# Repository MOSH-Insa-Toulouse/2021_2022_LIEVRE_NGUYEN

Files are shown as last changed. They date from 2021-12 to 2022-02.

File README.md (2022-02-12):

# 2021_2022_LIEVRE_NGUYEN
This project is part of the 5ISS year formation at INSA Toulouse. We created a nanoparticle gas sensor in the AIME laboratory at INSA Toulouse.
Then, we designed the PCB and the code to use the sensor with a  and display its data on a dashboard.

## SOMMAIRE 
1. [Introduction](#intro)
2. [Lora](#p2)
3. [LoraWAN](#p3)
4. [TTN](#p4)
5. [KiCad](#p5) 
6. [Node-RED](#p6)
7. [Datasheet](#p7)
8. [Possible improvements](#p8)
9. [Contacts](#p9)

## Introduction 

This project allowed us to go further in the development of our sensor. 
Indeed, we can now use it with a shield, connect it to TTN and see the data on a Node-RED dashboard. The arduino code used to retrieve and process the data was adapted for both the AIME gaz sensor and the industrial grove sensor given to us. We used a ESP32 as a microcontroller.

Here, you will find :

- [x] The arduino code of the sensor to collect data, alert the user and connect it to TTN.
- [x] The PCB shield along with the KiCad project.
- [x] The Node-RED flow for the dashboard.
- [x] The sensor's datasheet.

Here is a picture of our circuit: <br>
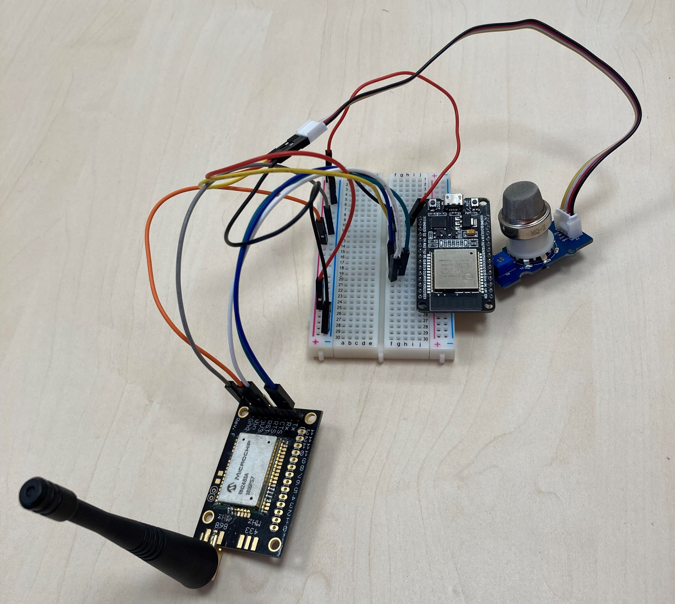
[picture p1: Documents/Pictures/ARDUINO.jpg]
 <br>

## Lora 

First, we tested the LoRa connexion with a small code.
To test it, we used a very simple circuit:
- RST connected to D21
- Rx connected to D19
- Tx connected to D18

You can find the code below:

<details>
  <summary><b>Tx</b></summary>
   To send a message, you need to enter the following command : "radio tx" + hexa_msg

```c++
  #include <Arduino.h>
  #include <HardwareSerial.h>
  #include "rn2xx3.h"

  #define RXD2 18
  #define TXD2 19
  #define RESET 21

  rn2xx3 lora(Serial2);

  void initialize_radio()
  {
    pinMode(RESET, OUTPUT);
    digitalWrite(RESET, LOW);
    delay(100);
    digitalWrite(RESET, HIGH);

    delay(100); //wait for the RN2xx3's startup message
    Serial2.flush();
  }

  void setup()
  {
    Serial.begin(9600);
    Serial2.begin(57600, SERIAL_8N1, RXD2, TXD2);
    initialize_radio();
    Serial.println(Serial2.readStringUntil('\n'));
    Serial2.print("radio set pwr 14\r\n");
    Serial.println(Serial2.readStringUntil('\n'));
    Serial2.print("mac pause\r\n");
    Serial.println(Serial2.readStringUntil('\n'));
  }

  void loop()
  {
    if(Serial2.available()) {
      Serial.println(Serial2.readStringUntil('\n'));
    }
    if (Serial.available())
    { 
      String Command = Serial.readStringUntil('\n');
      Serial.println(Command);
      Serial2.print(Command + "\r\n");
    }
  }
```
</details>

<details>
  <summary><b>Rx</b></summary>

``` c++
  #include <Arduino.h>
  #include <HardwareSerial.h>
  #include "rn2xx3.h"

  #define RXD2 18
  #define TXD2 19
  #define RESET 21

  rn2xx3 lora(Serial2);

  void initialize_radio()
  {
    //reset RN2xx3
    pinMode(RESET, OUTPUT);
    digitalWrite(RESET, LOW);
    delay(100);
    digitalWrite(RESET, HIGH);

    delay(100); //wait for the RN2xx3's startup message
    Serial2.flush();
  }

  void setup()
  {
    Serial.begin(9600);
    Serial2.begin(57600, SERIAL_8N1, RXD2, TXD2);
    initialize_radio();
    Serial.println(Serial2.readStringUntil('\n'));
    Serial2.print("radio set pwr 14\r\n");
    Serial.println(Serial2.readStringUntil('\n'));
    Serial2.print("mac pause\r\n");
    Serial.println(Serial2.readStringUntil('\n'));
  }

  void loop()
  {
    Serial2.print("radio rx 0\r\n");
    if(Serial2.available()) {
      Serial.println(Serial2.readStringUntil('\n'));
    }
    if (Serial.available())
    { 
      String Command = Serial2.readStringUntil('\n');
      Serial.println(Command);
    }
    delay(1000);
  }
```
</details>

You can also find the codes:
- [here for Tx](https://github.com/MOSH-Insa-Toulouse/2021_2022_LIEVRE_NGUYEN/tree/main/Piste_verte/Lora_Tx_mod2mod.ino)
- [here for Rx](https://github.com/MOSH-Insa-Toulouse/2021_2022_LIEVRE_NGUYEN/tree/main/Piste_verte/Lora_Rx_mod2mod.ino)

## LoraWAN 

In this part, we implemented the full arduino code that retrieves and sends to TTN via LoraWAN the value of both the grove and AIME sensor. 
We also read the raw value of the resistor (R_alu) that serves as a temperature sensor. By using the R_alu value, we then deduced the temperature.
We also implemented a PID controller to maintain the temperature of the silicium resistor R_Poly to a temperature of 200°C. To do so, we use the PID controller to generate a duty cycle that is then entered as a parameter for the PWM signal that controls the silicium rod that serves as R_poly.

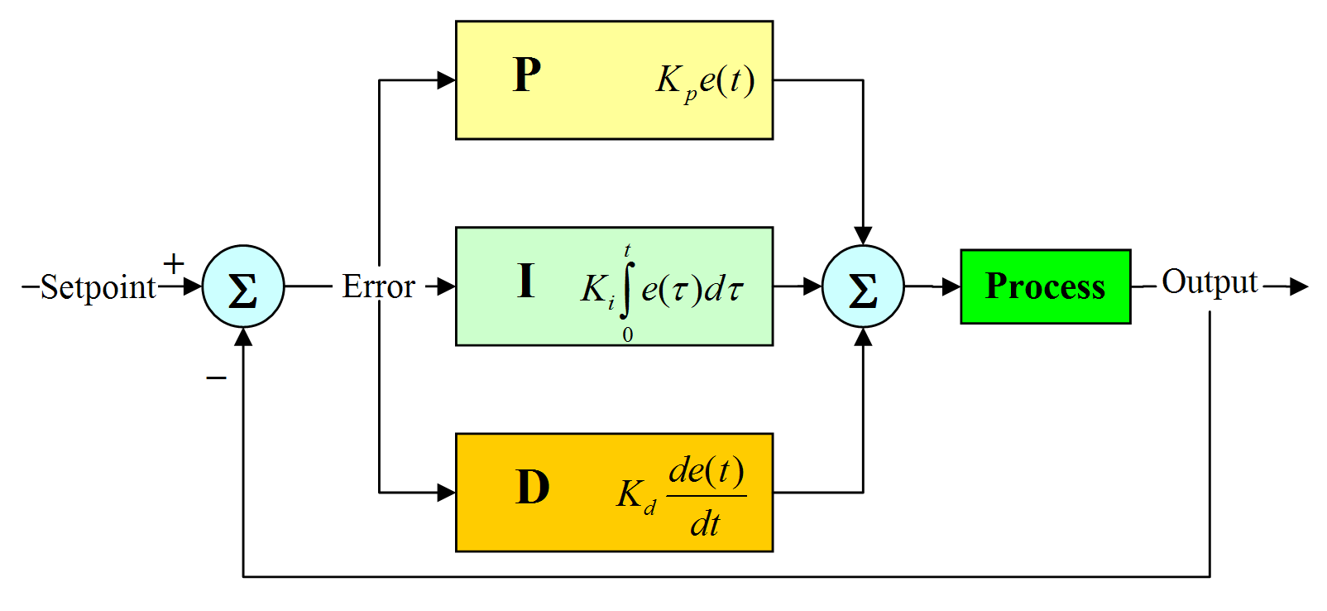
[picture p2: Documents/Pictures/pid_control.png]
 <br>

<details>
  <summary><b>You can find the code directly here</b></summary>

```c++
  #include <Arduino.h>
  #include "rn2xx3.h"

  #define RESET 21 //Pin Reset LoRA
  #define RX 18    //Pin RX LoRa
  #define TX 19    //Pin TX LoRa
  #define INTERRUPT_PIN 12 //Pin d'interruption du capteur de gaz grove
  #define PWM_PIN 16   //Pin de sortie de la commande PWM (vers transistor -> R_poly (barreau silicium))
  #define GROVE_PIN 4  //Signal d'entree du capteur grove 
  #define CMD_R_POLY 7 //Pin de la sortie de commande de la resistance de chauffe (barreau silicium)
  #define ADC_SENSOR 33 // Pin d'entree du signal du capteur de gaz (AIME)
  #define ADC_R_ALU 27 //Pin d'entree de la resistance d'aluminium (capteur de temperature)
  #define BUZZER_PIN 17  //Pin de sortie du buzzer

  #define gaz_threshold 1E8 //Valeur seuil pour déclencher l'alarme (buzzer)
   
  //Correcteur PID
  float e_curr = 0; //erreur à t
  float e_prev = 0; //erreur à t-1
  int prev_T = 0; //timestamp 1
  int curr_T = 0; //timestamp 2
  float target_temp = 200; // Température de R_poly voulue

  //Paramètres TTN
  String AppEUI = "0000000000000000";
  String AppKey = "27C93ED04348754075826C46CE00F53D";

  //Capteur de température (Alu)
  int a; //
  int b; // R_aluminium = a * T(Kelvin) + b 

  // Pour la commande PWM de la résistance de chauffe
  int duty_cycle; //duty cycle du signal PWM pour la commande de la résistance de chauffe
  const uint32_t PWM_fq = 20000;
  const uint32_t PWMChannel = 0;
  const uint32_t resolution = 8;

  // Pour le capteur grove
  float sensor_grove_volt; //conversion en volt de l'entree du signal du capteur grove
  float RS_gas; //valeur de RS dans le gaz
  float R0 = 1.7; //résistance du module grove en environnement ambiant 
  float ratio; // ratio RS_GAS/RS_air
  uint32_t ratio_int;
  uint32_t grove_data; //données capteur grove

  // Pour le capteur AIME
  float sensor_aime_volt; //conversion en volt de l'entree du signal du capteur AIME
  uint32_t AIME_data;  //données capteur AIME
  int R1 = 100000;
  int R2 = 1000;
  int R3 = 100000;
  int R4;
  int R5 = 10000;
  int R6; //resistances du circuit de conditionnement (cf circuit Kicad)
  int Vcc; // à definir en fonction des grandeurs electriques voulues

  rn2xx3 lora(Serial2); //Constructeur de la classe rn2xx3

  //Initialisation du module LoRa
  void init_Lora(){
    
    //reset RN2xx3
    pinMode(RESET, OUTPUT);
    digitalWrite(RESET, LOW);
    delay(100);
    digitalWrite(RESET, HIGH);
    delay(100); //Attente le startup message du module RN2xx3 
    Serial2.flush();
    //Vérification de la communication avec la radio
    String hweui = lora.hweui();
    while (hweui.length() != 16)
    {
      Serial.println("Communication with RN2xx3 unsuccessful. Power cycle the board.");
      Serial.println(hweui);
      delay(10000);
      hweui = lora.hweui();
    }

    //Retourne le HWEUI pour l'inscrire via ttnctl
    Serial.println("When using OTAA, register this DevEUI: ");
    Serial.println(hweui);
    Serial.println("RN2xx3 firmware version:");
    Serial.println(lora.sysver());
    
    Serial.println("Trying to join TTN");
    bool join_result = false;
    //OTAA: initOTAA(String AppEUI, String AppKey);
    join_result = lora.initOTAA(AppEUI, AppKey);

    while (!join_result)
    {
      Serial.println("Unable to join. Are your keys correct, and do you have TTN coverage?");
      delay(60000); //Attente d'une minute avant de réessayer
      join_result = lora.init();
    }
    Serial.println("Successfully joined TTN");
  }

  //Lecture du capteur grove
  uint32_t read_grove() 
  {
    int sensor_grove_value = analogRead(GROVE_PIN); 
    sensor_grove_volt=(float)sensor_grove_value/4096*5.0; //tension du capteur
    RS_gas = (5.0-sensor_grove_volt)/ sensor_grove_volt; // taux de variation de la résistance selon le gaz
    ratio = (RS_gas/R0);  // ratio = RS/R0
    uint32_t data_sensor = ratio*100;
    return data_sensor;
  }

  //Lecture du capteur AIME
  uint32_t read_AIME(){ 
    
    int sensor_aime_value = analogRead(ADC_SENSOR);
    sensor_aime_volt=(float)sensor_aime_value/4096*5.0;
    float R_sensor=(R1*(R2+R3)*Vcc/(R2*sensor_aime_volt))-R1-R5; 
    return R_sensor;
  }

  //Lecture de la résistance du capteur de température
  uint32_t read_r_alu (){
    int adc_R_alu = analogRead(ADC_R_ALU);
    float adc_R_alu_volt=(float)ADC_R_ALU/4096*3.3;
    float R_Alu=adc_R_alu_volt*R6/(3.3-adc_R_alu_volt);
    return R_Alu;
  }

  //Calcul de la temperature du capteur avec R aluminium
  float read_temperature(){
    
    float temp = a*(read_r_alu()) + b;
    temp = temp - 273; //conversion en C°
    return temp;
  }

  //Correcteur PID pour maintenir la température du R_poly à 200 °C
  int corr_PID(int Kp, int Ki, int Kd){

    int curr_T = micros();
    float delta_t=((float)(curr_T - prev_T))/1E6; 
    e_curr = target_temp - read_temperature(); 
    float e_P = e_curr; //partie proportionnelle
    float e_I = (e_I + e_curr * delta_t); //partie intégrale
    float e_D = (e_curr - e_prev) / (delta_t); //partie dérivatrice
    prev_T = curr_T;
    e_prev = e_curr;
    uint8_t C = Kp * e_P + Ki * e_I+ Kd * e_D;
    if(C > 255) {
      C = 255; //Pour borner la correction entre 0 et 255
    }
    return C; //Duty cycle de la PWM de commande
   
  }

  //Configuration PWM
  void config_PWM(){
    pinMode(PWM_PIN,OUTPUT);
    ledcSetup(PWMChannel, PWM_fq, resolution);
    ledcAttachPin(PWM_PIN, PWMChannel); //Liaison de la channel avec le pin PWM pour le contrôler
  }

  //Commande de la resistance de chauffe en PWM
  void cmd_PWM_Poly(){
    int duty_cycle=corr_PID(1,0,0);
    ledcWrite(PWMChannel,duty_cycle);
  }

  void setup() {
    Serial.begin(9600);
    config_PWM(); 
    Serial2.begin(57600, SERIAL_8N1, RX, TX);
    init_Lora();
    if (Serial.available()){
      Serial2.print("sys get hwei\r\n"); // recuperation du HWEUI
      Serial.println(Serial2.readStringUntil('\n'));
    }
    digitalWrite(BUZZER_PIN, 0); //inititialisation du buzzer
    
  }

  void loop() {

    cmd_PWM_Poly();
    grove_data=read_grove();
    AIME_data=read_AIME();
    if(AIME_data > gaz_threshold){

      byte payload[4]; //Payload a envoyer sur TTN
      payload[0] = highByte(grove_data);
      payload[1] = lowByte(grove_data);
      payload[2]=highByte(AIME_data);  
      payload[1]=lowByte(AIME_data);
      lora.txBytes(payload,4); 
      
      for (int i=0;i<5; i++){
        digitalWrite(BUZZER_PIN, 1); //active l'alarme à la detection de gaz
        delay(10000);
      }
      digitalWrite(BUZZER_PIN, 0); //inititialisation du buzzer
    
    }
    
  }
```
</details>

You can also find the code [here](https://github.com/MOSH-Insa-Toulouse/2021_2022_LIEVRE_NGUYEN/tree/main/Piste_rouge/Piste_bleue_code)

## TTN 

We configured an application whose overview is shown in the next picture:

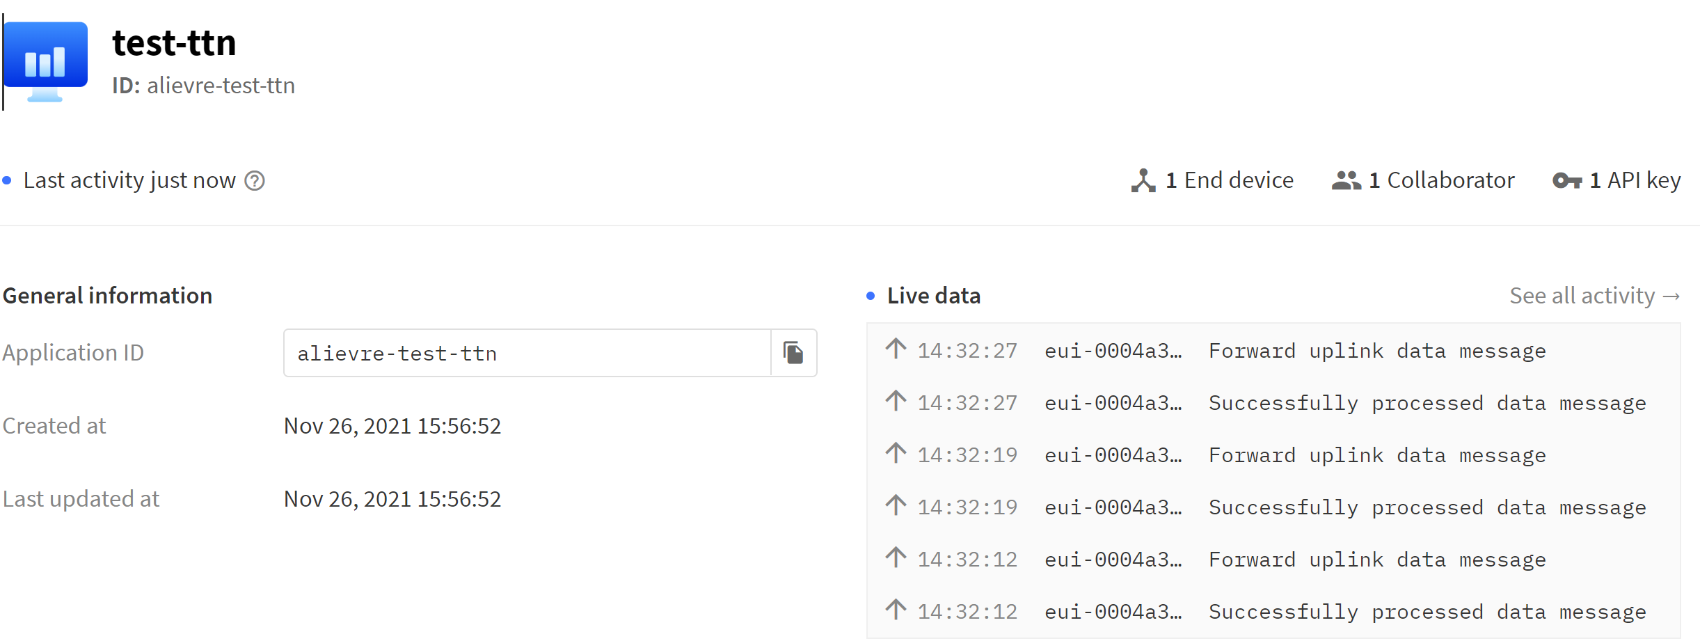
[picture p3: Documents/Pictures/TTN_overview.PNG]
TTN_overview


In this app, we added a device:

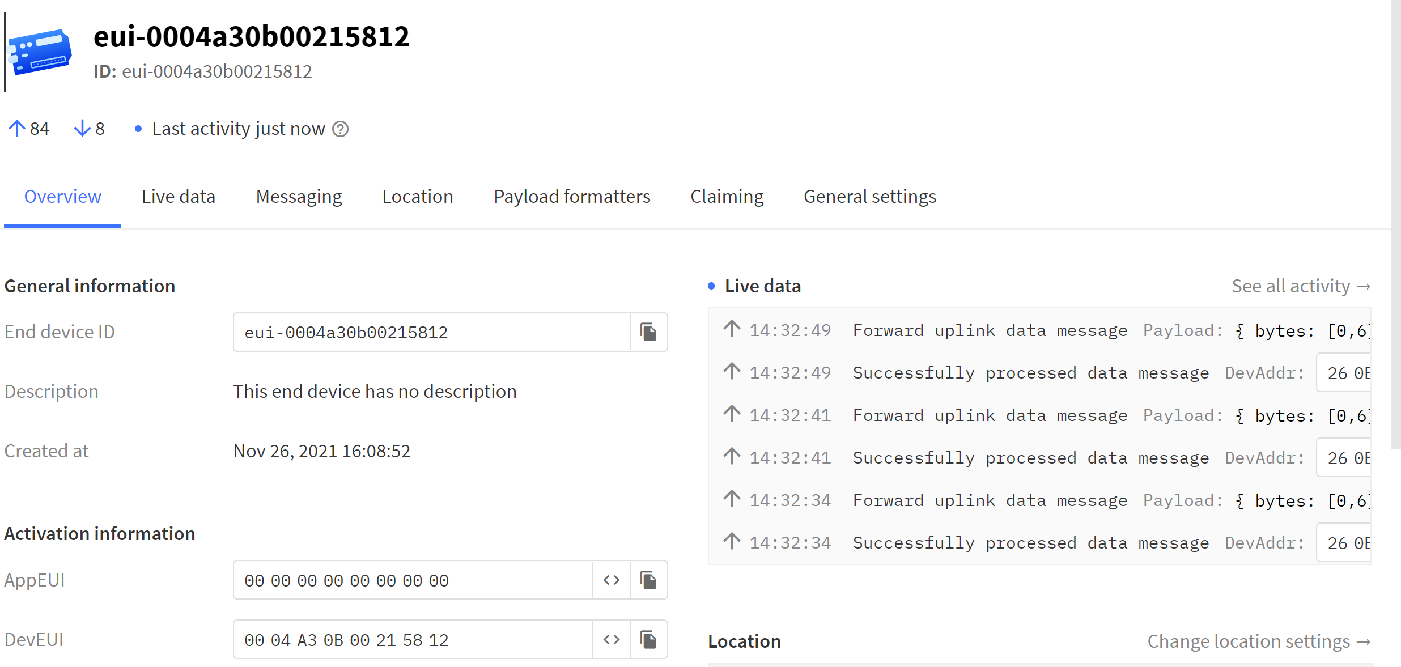
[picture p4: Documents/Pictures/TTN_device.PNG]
TTN_device

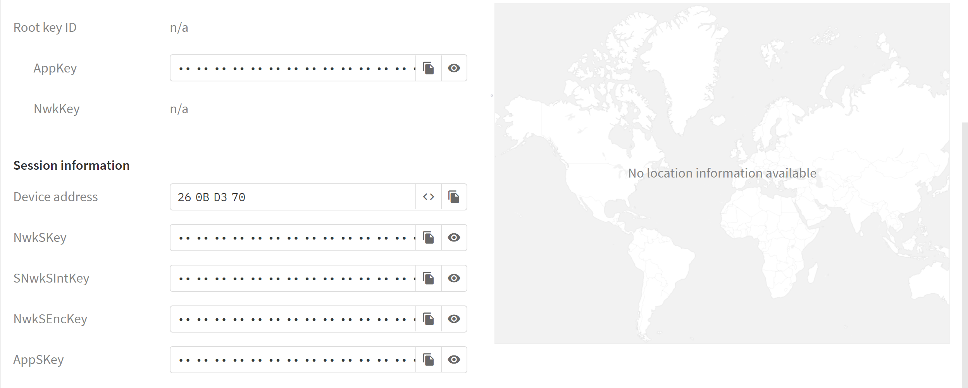
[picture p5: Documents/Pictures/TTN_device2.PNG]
TTN_device2


You can see that we received live data:

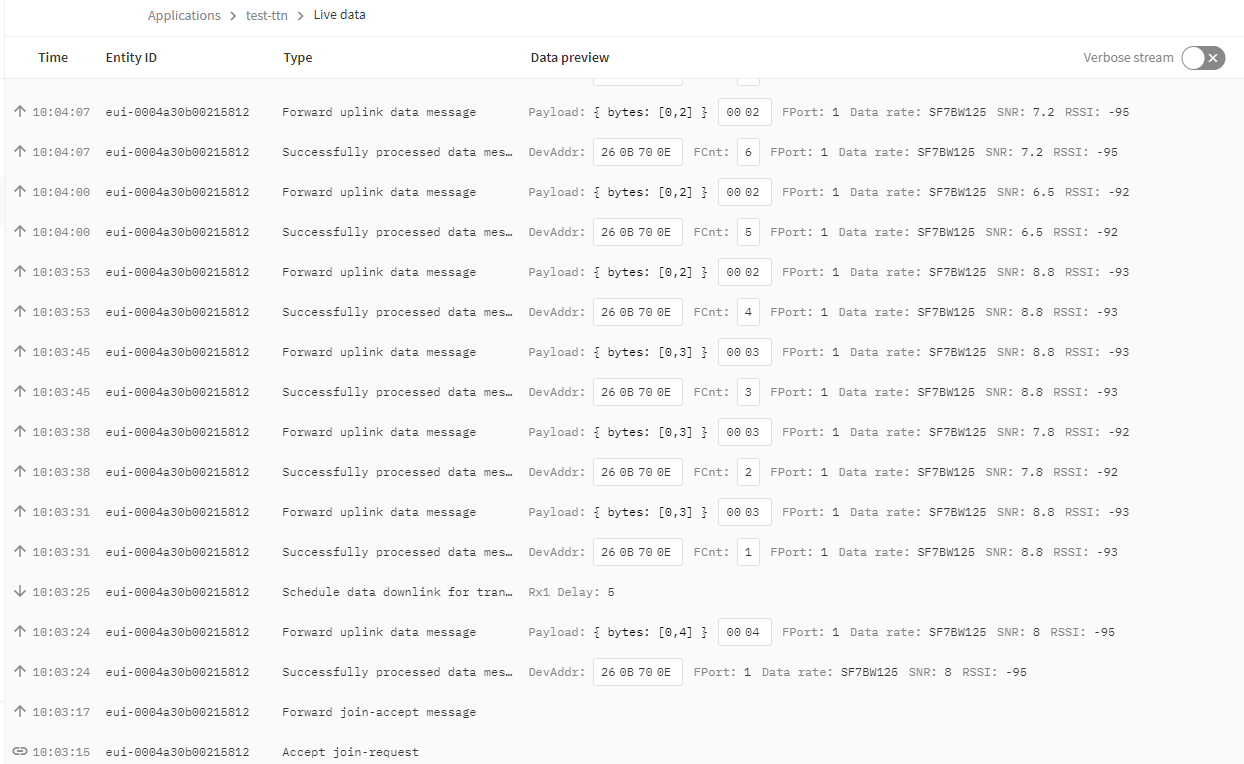
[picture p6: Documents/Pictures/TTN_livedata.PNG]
TTN_livedata


We also added a payload formatter: <br>

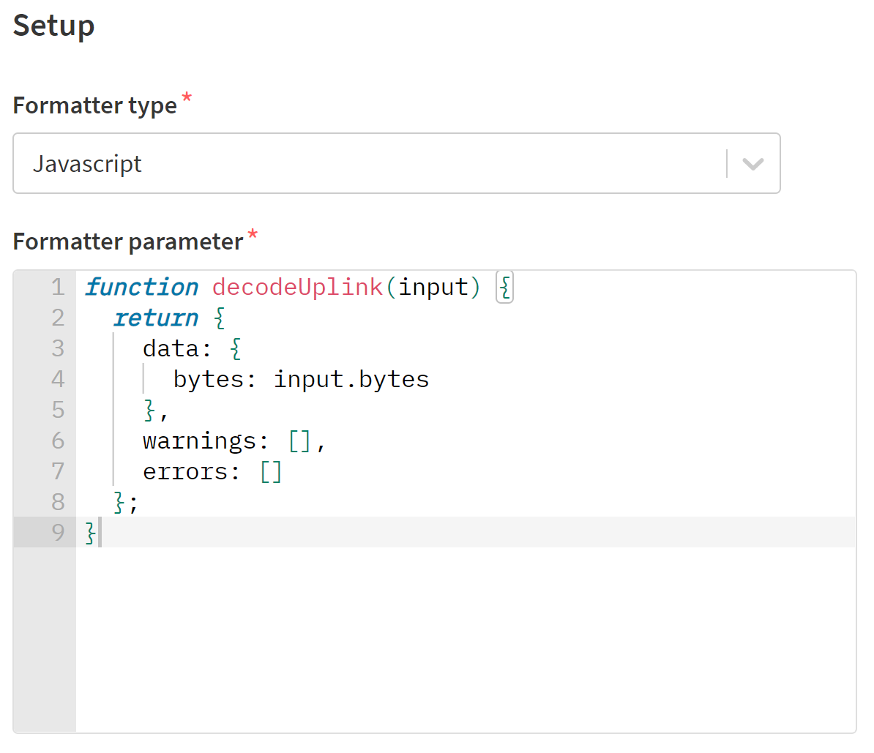
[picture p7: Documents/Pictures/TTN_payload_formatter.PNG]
 <br>

## KiCad 

We then proceeded to conceive the PCB shield.
The first thing to do is to draw the circuit. We used the following circuit:
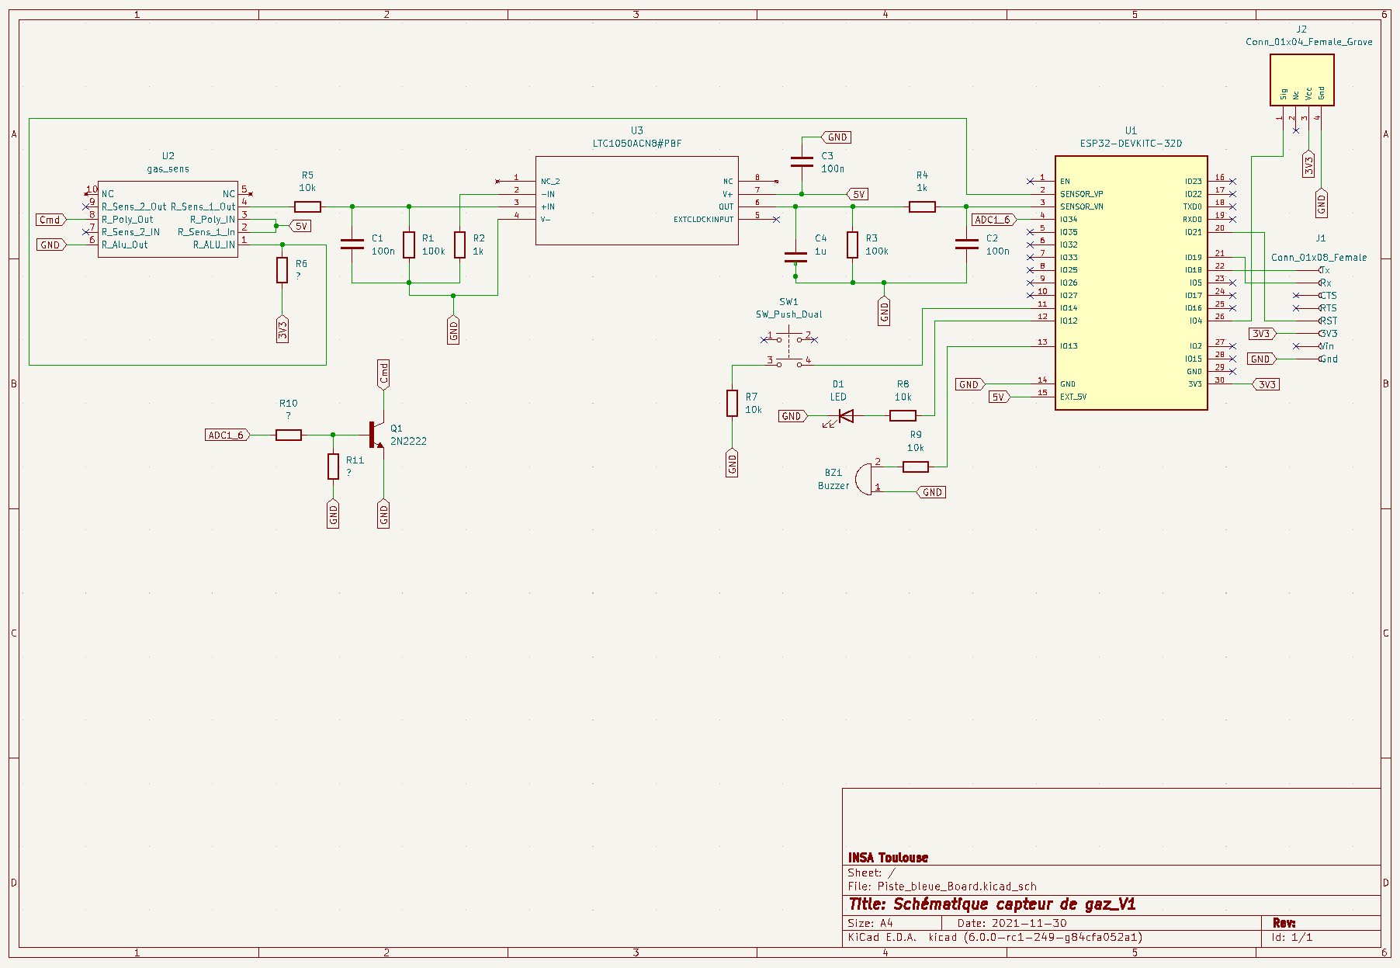
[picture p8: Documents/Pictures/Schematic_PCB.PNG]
Schematic_PCB


Then, we needed the footprint of each elements. <br> <br>
- Buzzer

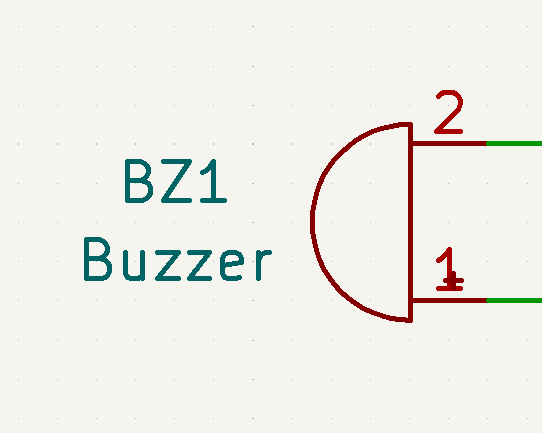
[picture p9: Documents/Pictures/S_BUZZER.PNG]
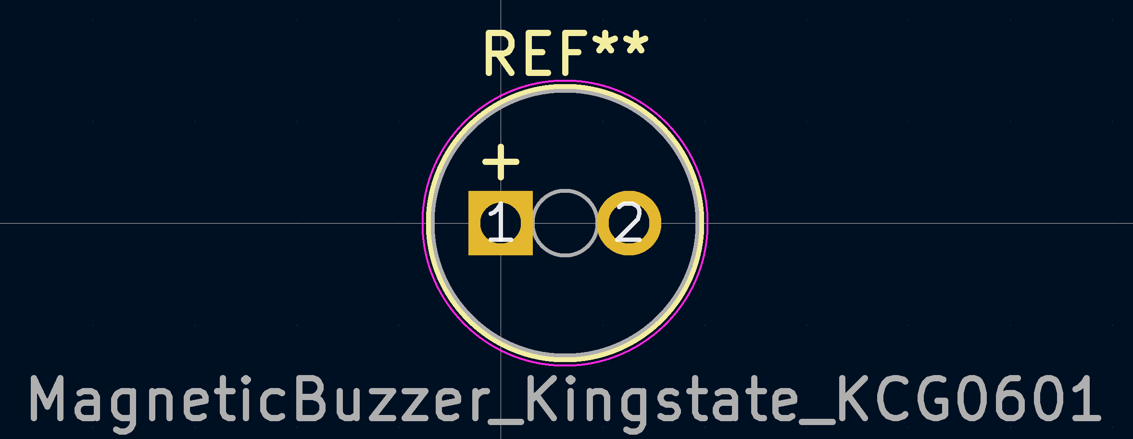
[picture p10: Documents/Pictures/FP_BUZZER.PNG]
 &emsp;  <br>

- Capacitor

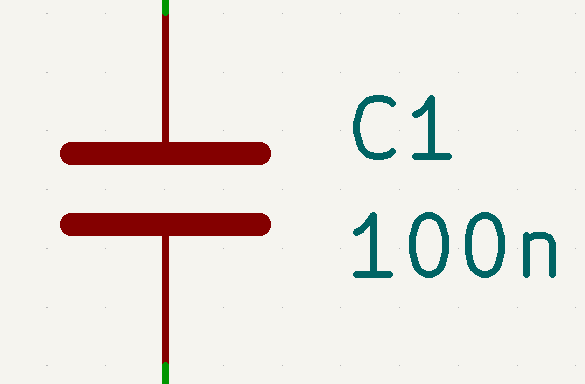
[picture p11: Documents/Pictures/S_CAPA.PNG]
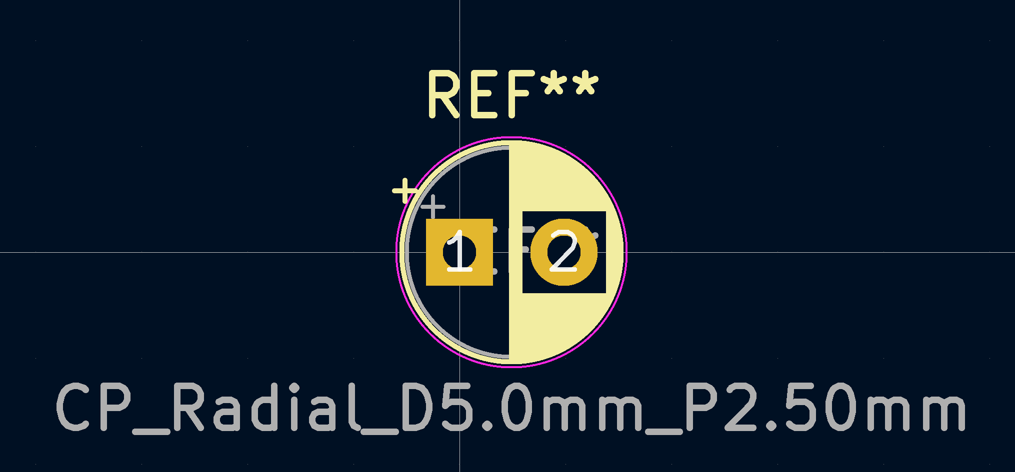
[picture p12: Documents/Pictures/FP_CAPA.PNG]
 &emsp;  <br>

- Connector 01x08

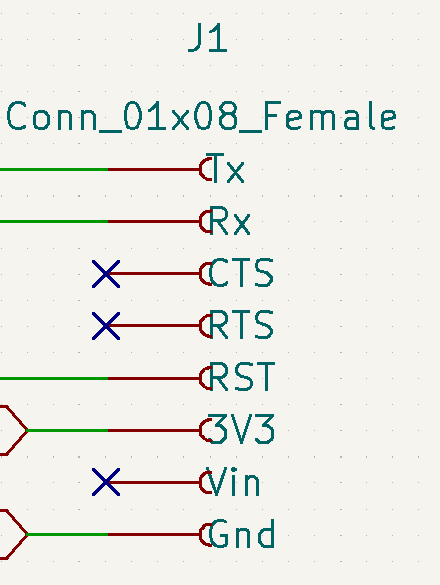
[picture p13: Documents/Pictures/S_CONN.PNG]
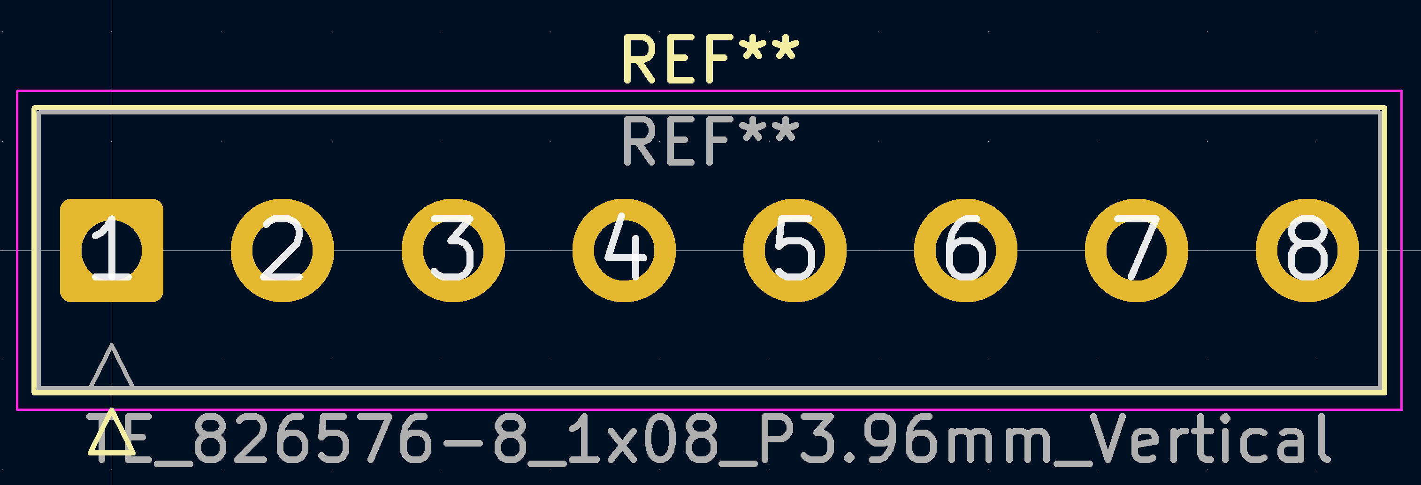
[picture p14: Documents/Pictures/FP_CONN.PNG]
 &emsp;  <br>

- Connector Grove 01x04

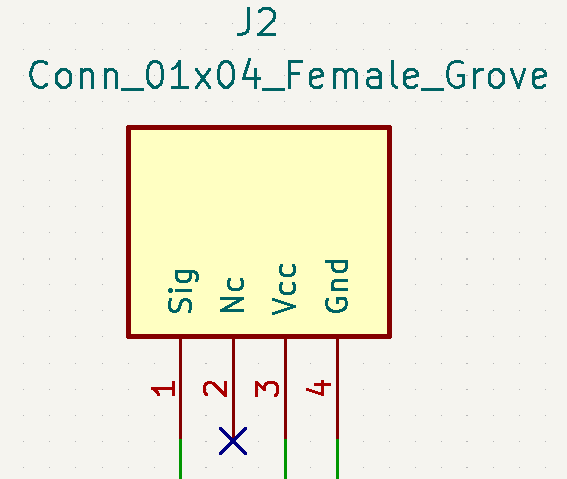
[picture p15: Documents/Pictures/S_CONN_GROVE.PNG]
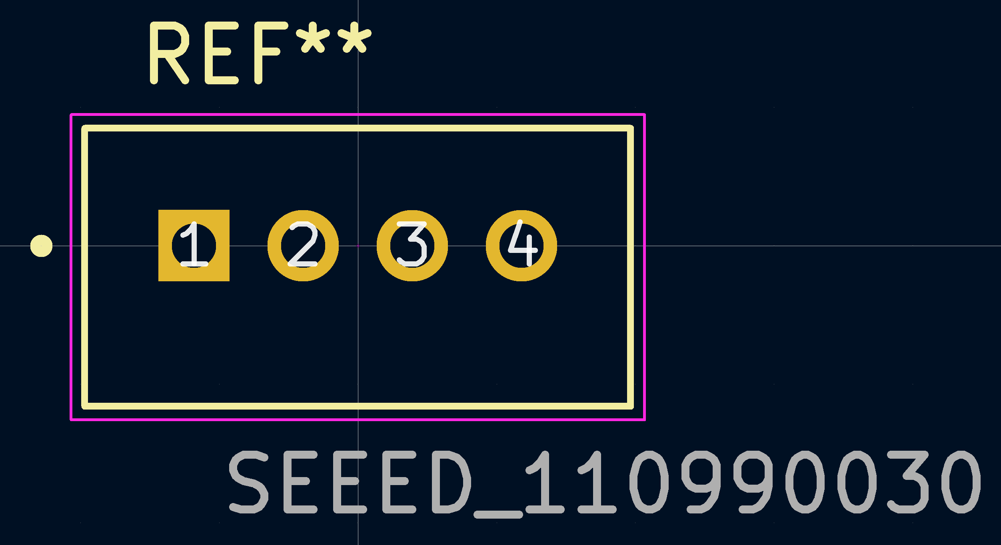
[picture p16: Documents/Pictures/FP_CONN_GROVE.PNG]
 &emsp;  <br>

- ESP32

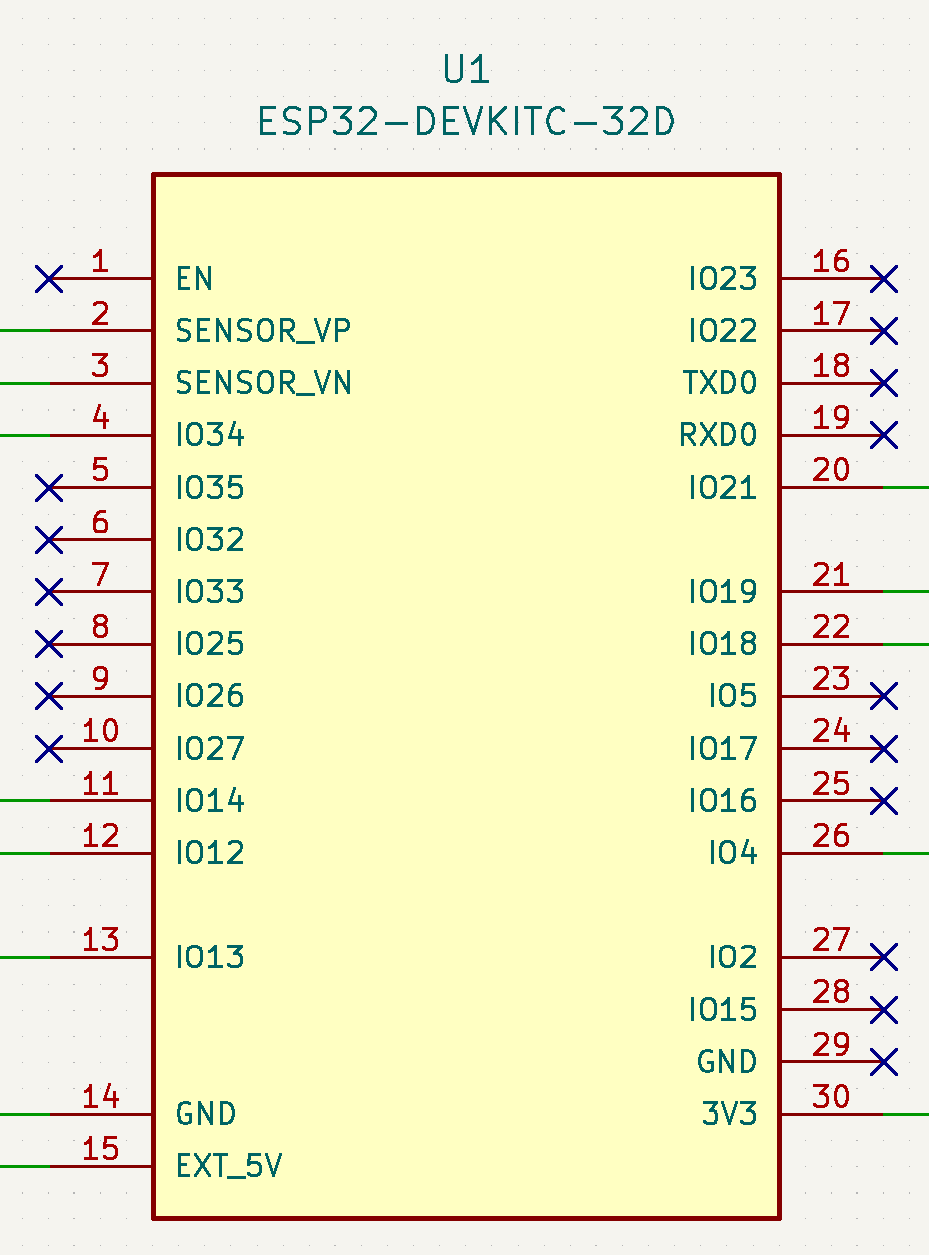
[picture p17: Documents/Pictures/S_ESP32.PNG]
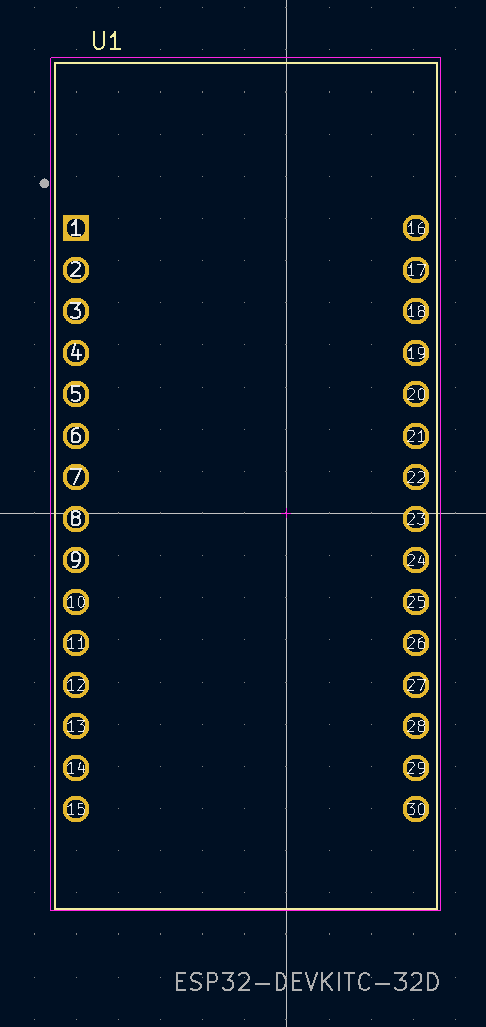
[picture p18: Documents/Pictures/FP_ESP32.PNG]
 &emsp;  <br>

- Gas Sensor

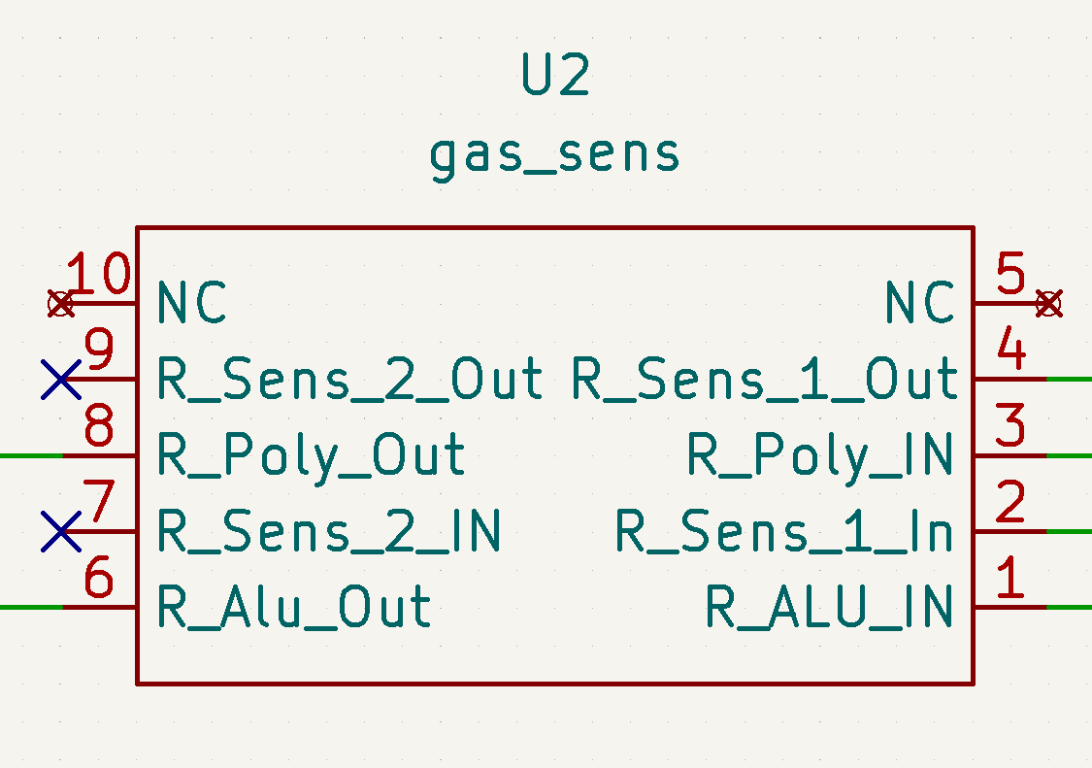
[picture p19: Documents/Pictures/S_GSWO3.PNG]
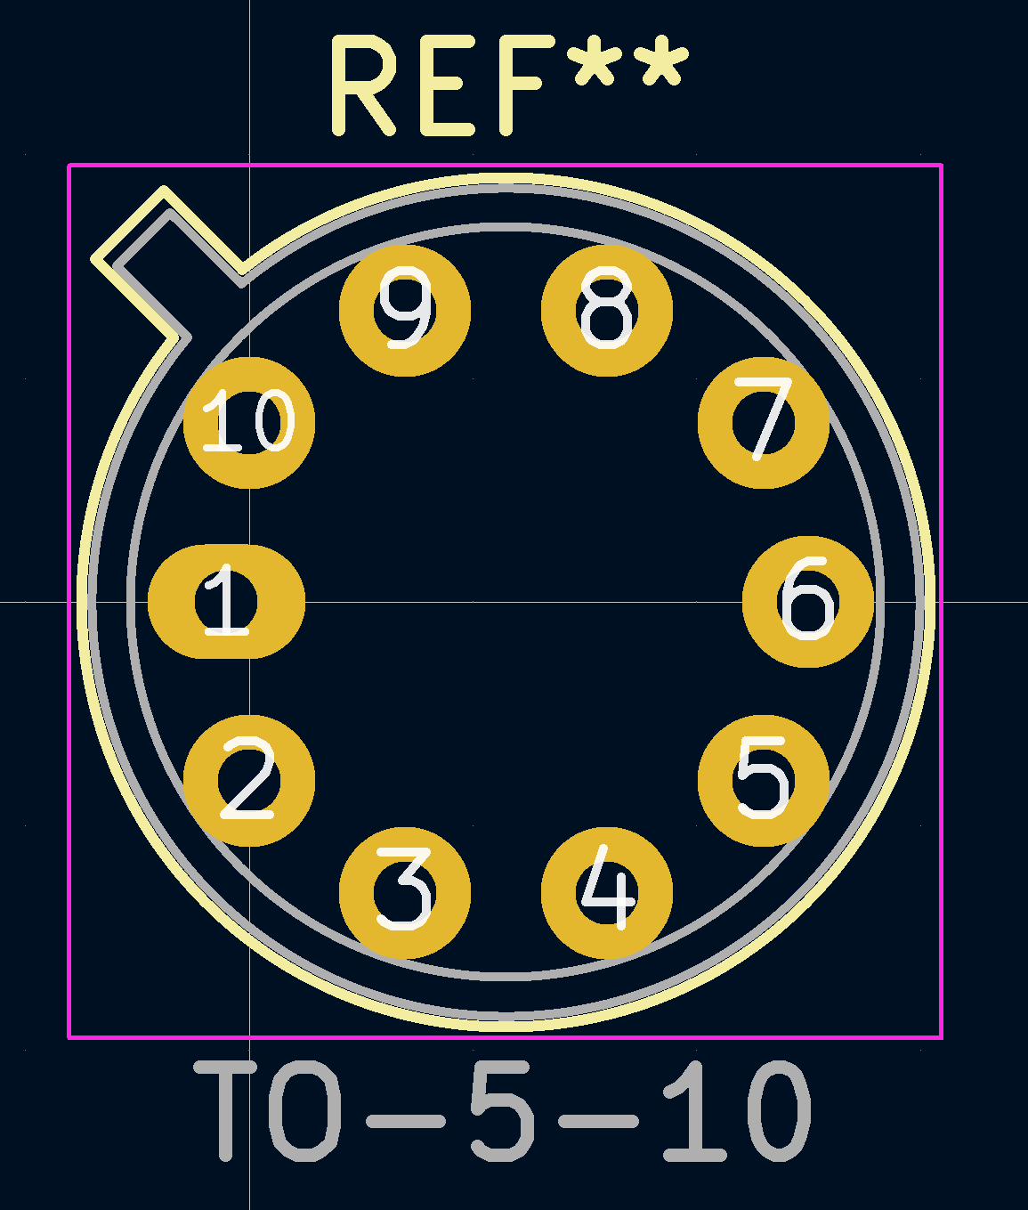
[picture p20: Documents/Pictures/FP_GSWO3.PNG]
 &emsp;  <br>

- LED

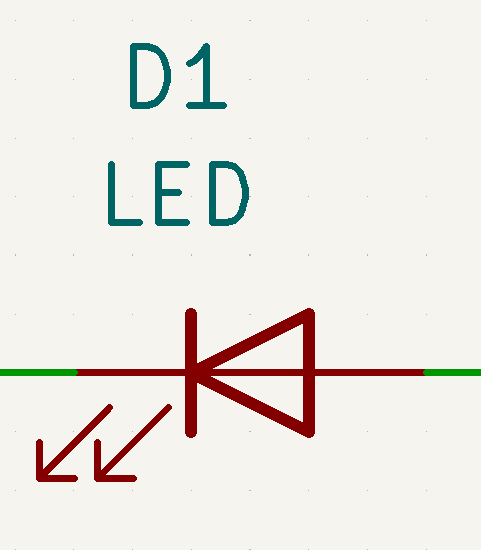
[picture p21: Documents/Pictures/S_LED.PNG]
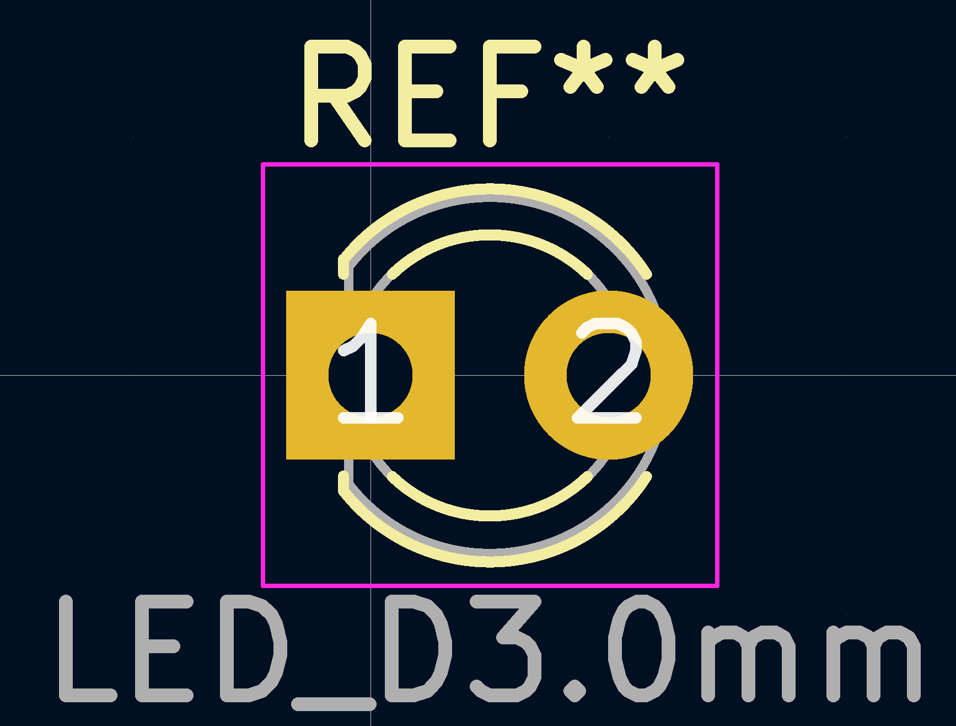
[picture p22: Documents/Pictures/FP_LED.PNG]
 &emsp;  <br>

- LTC

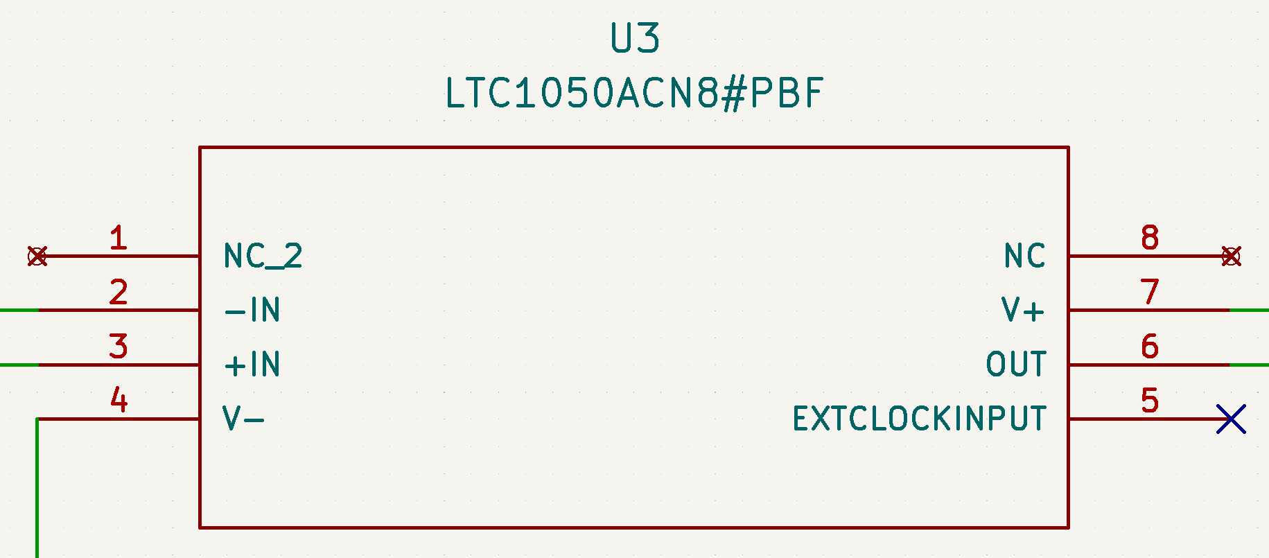
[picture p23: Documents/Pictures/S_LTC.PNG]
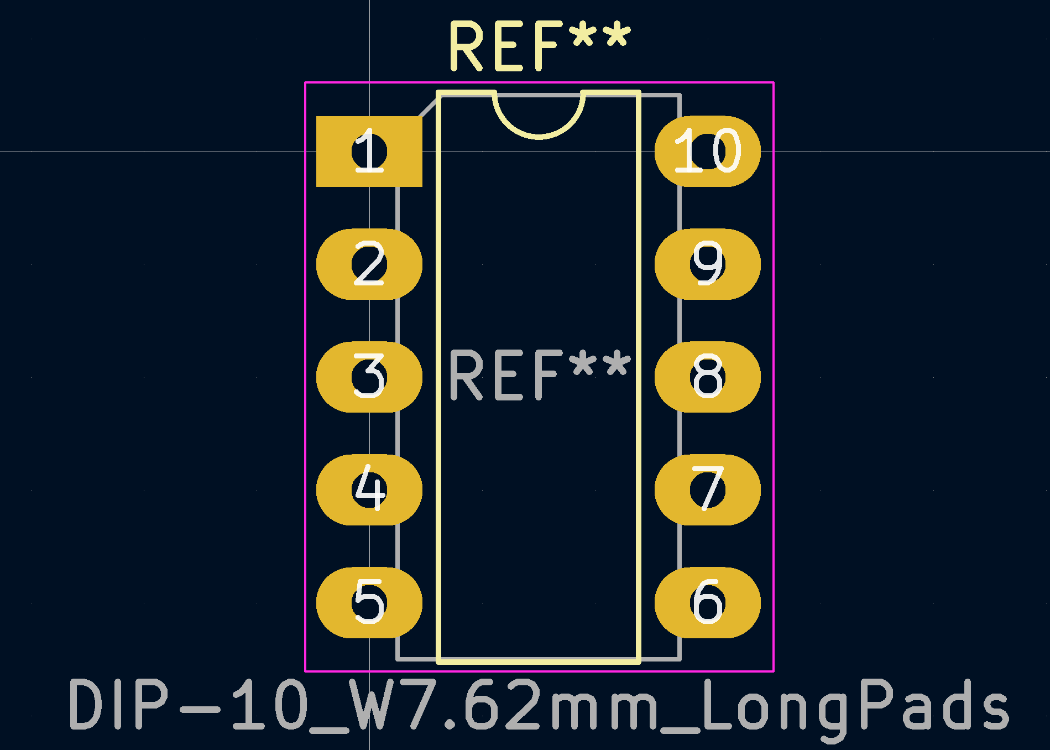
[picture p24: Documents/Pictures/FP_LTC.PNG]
 &emsp;  <br>

- Resistor

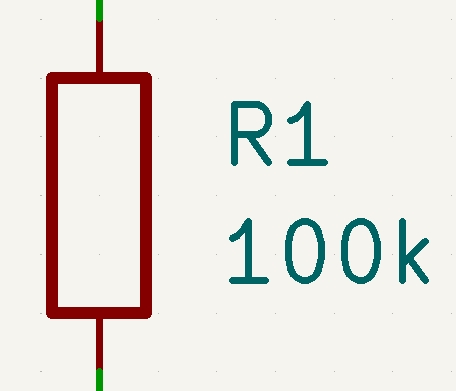
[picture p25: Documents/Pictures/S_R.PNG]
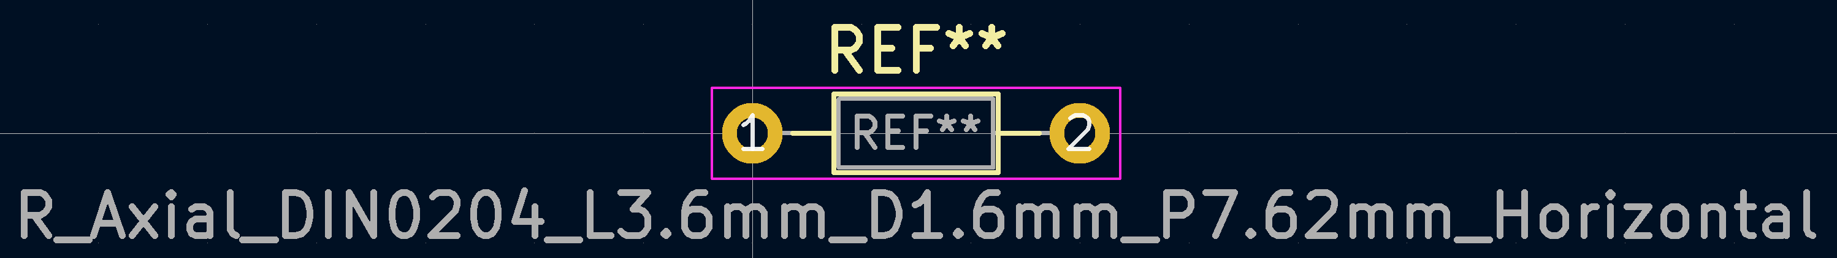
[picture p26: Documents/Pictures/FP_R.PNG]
 &emsp;  <br>

- Switch

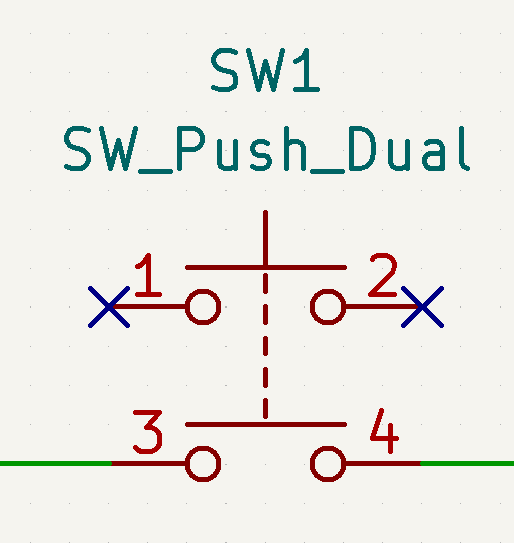
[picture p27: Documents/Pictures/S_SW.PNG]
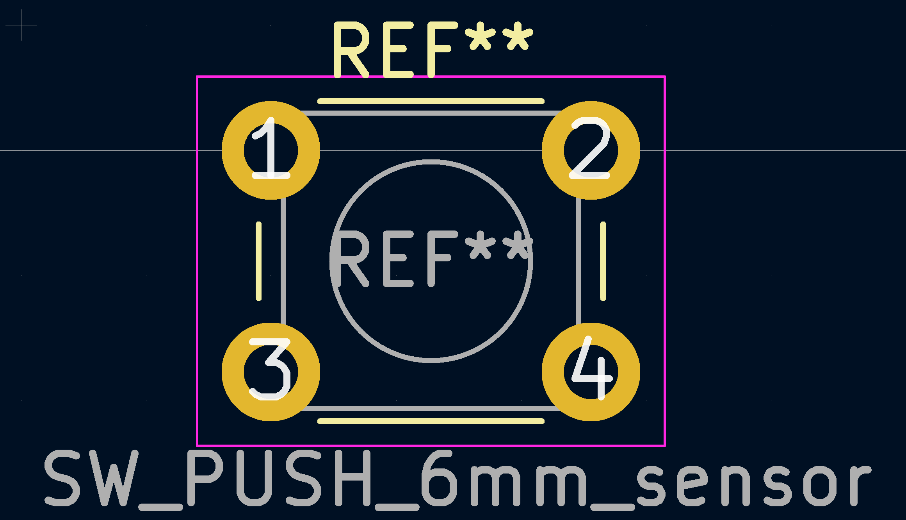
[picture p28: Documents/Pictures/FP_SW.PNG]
 &emsp;  <br>

- Transistor

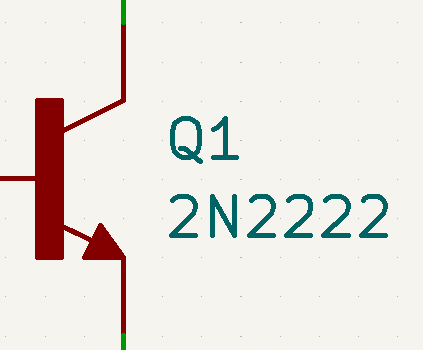
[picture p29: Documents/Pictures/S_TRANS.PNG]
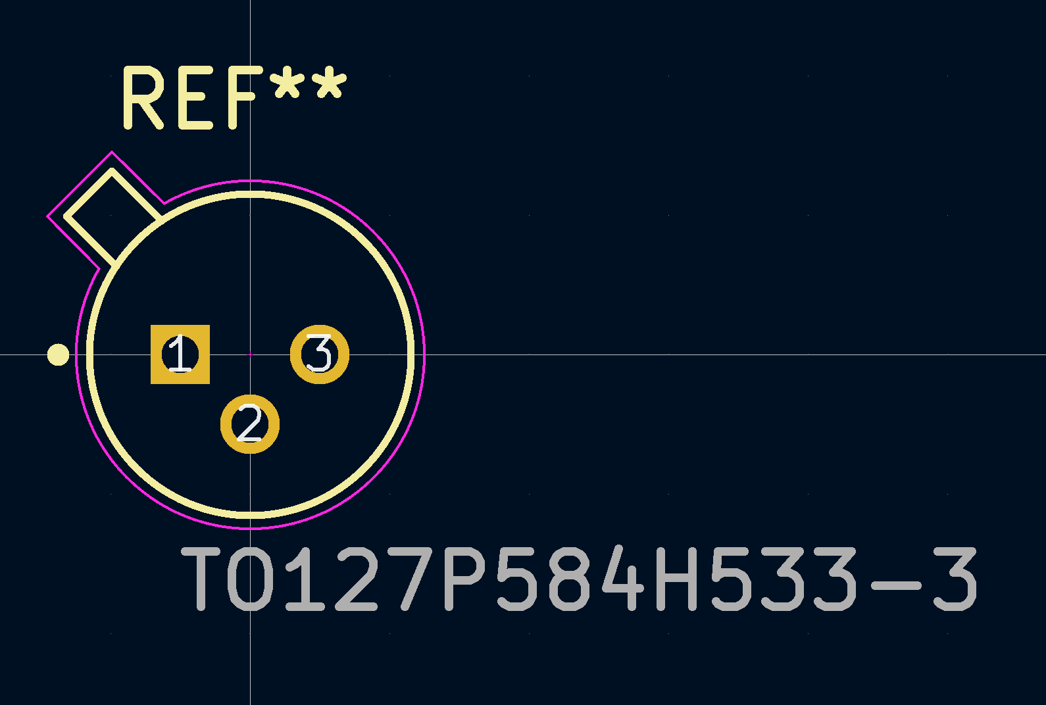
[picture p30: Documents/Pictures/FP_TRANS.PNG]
 &emsp;  <br>

Finally, we designed the PCB. Here, you have a picture of the schematics and the 3D view:
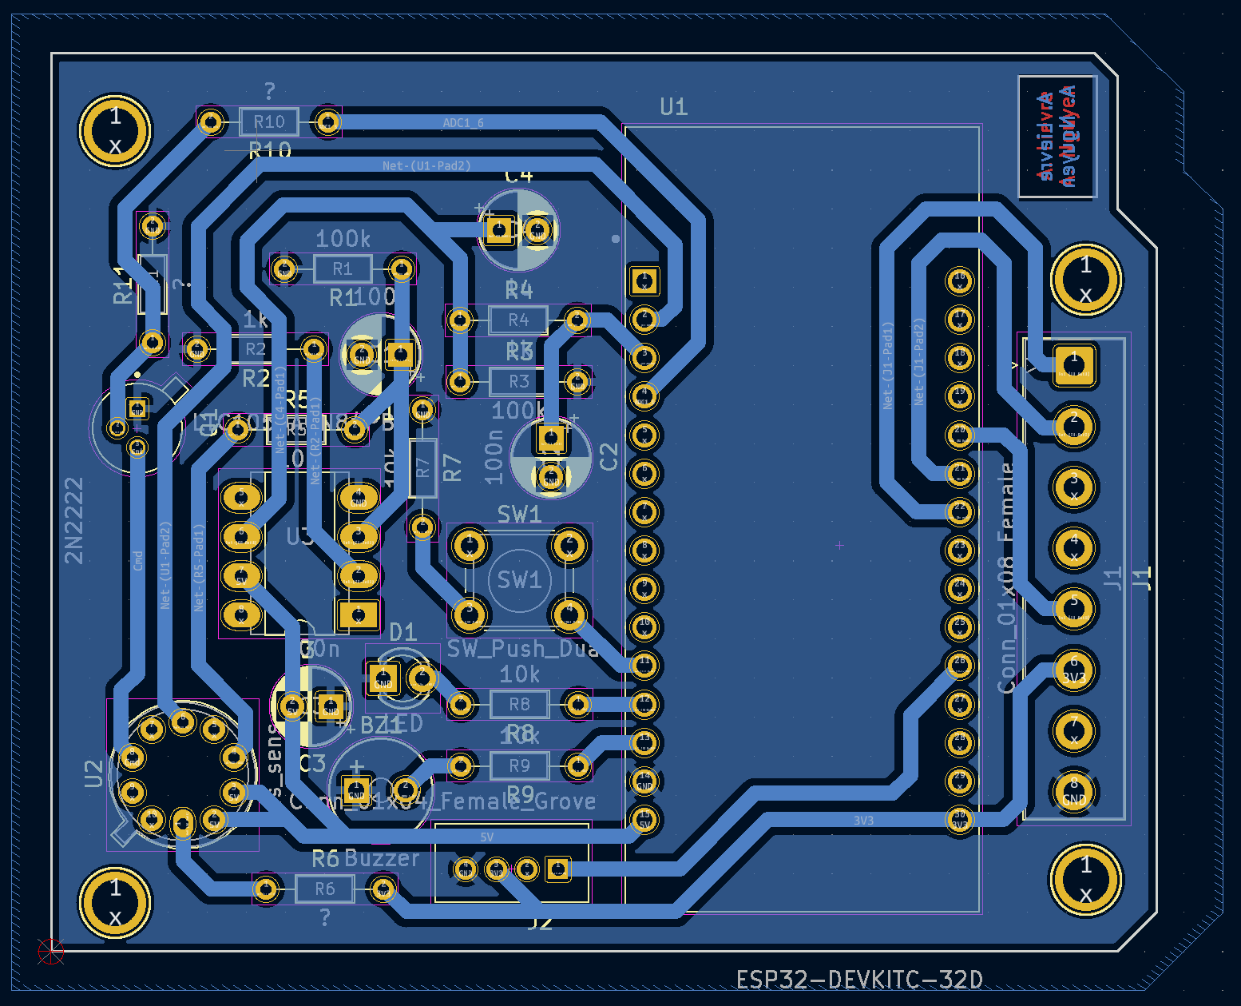
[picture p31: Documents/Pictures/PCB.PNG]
PCB

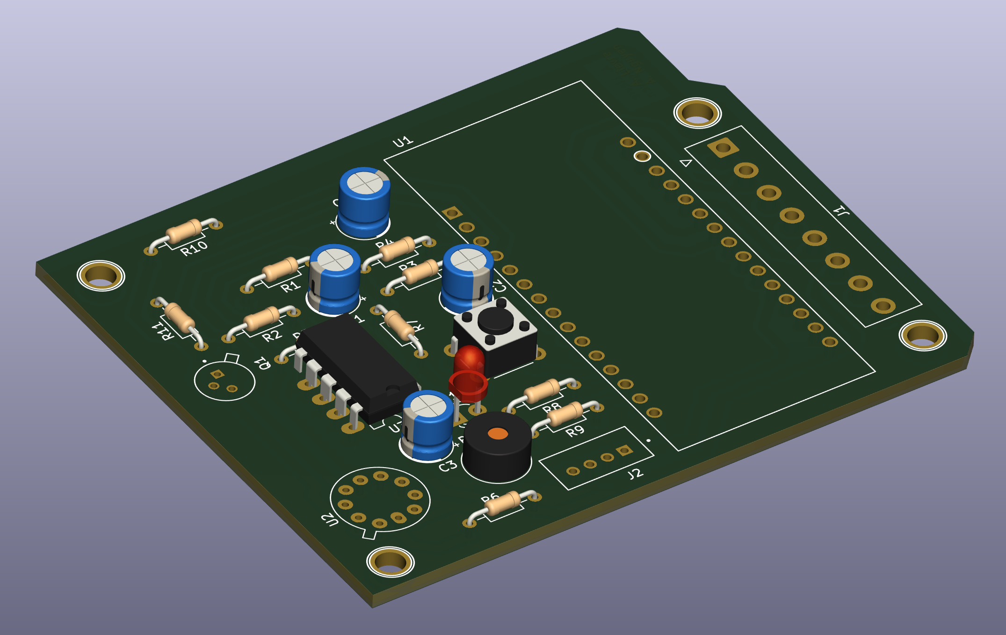
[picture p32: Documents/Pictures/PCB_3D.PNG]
PCB_3D

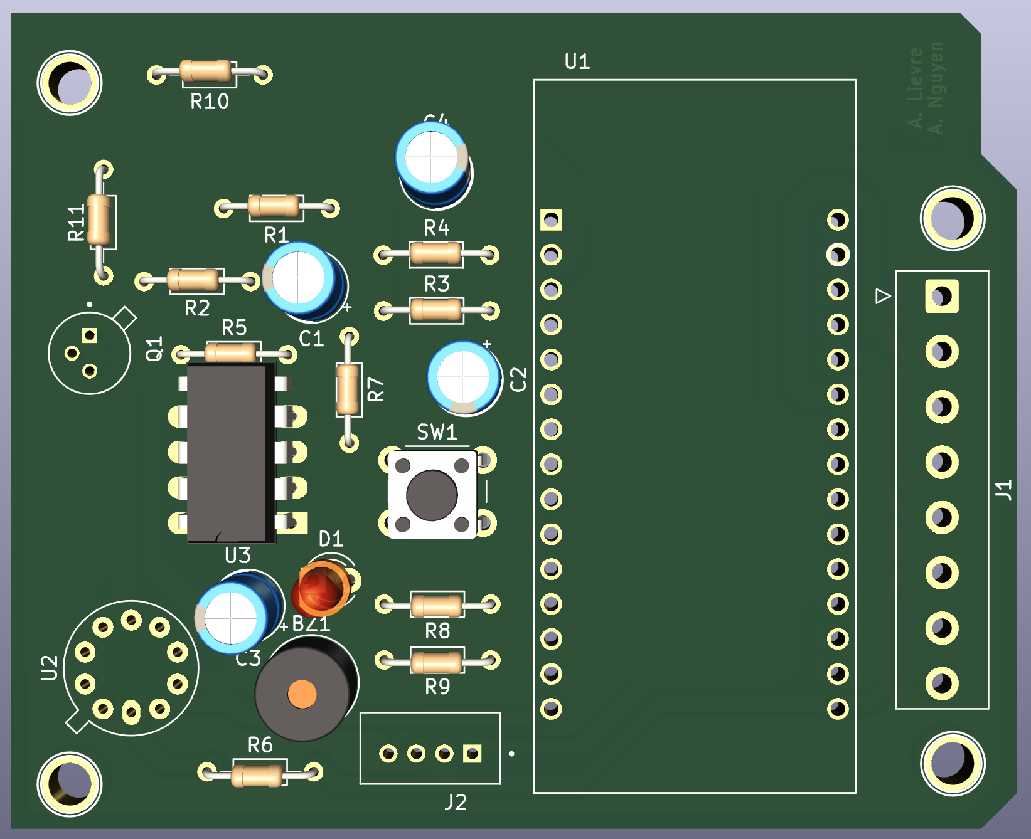
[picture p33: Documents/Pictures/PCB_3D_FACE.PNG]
PCB_3D_FACE

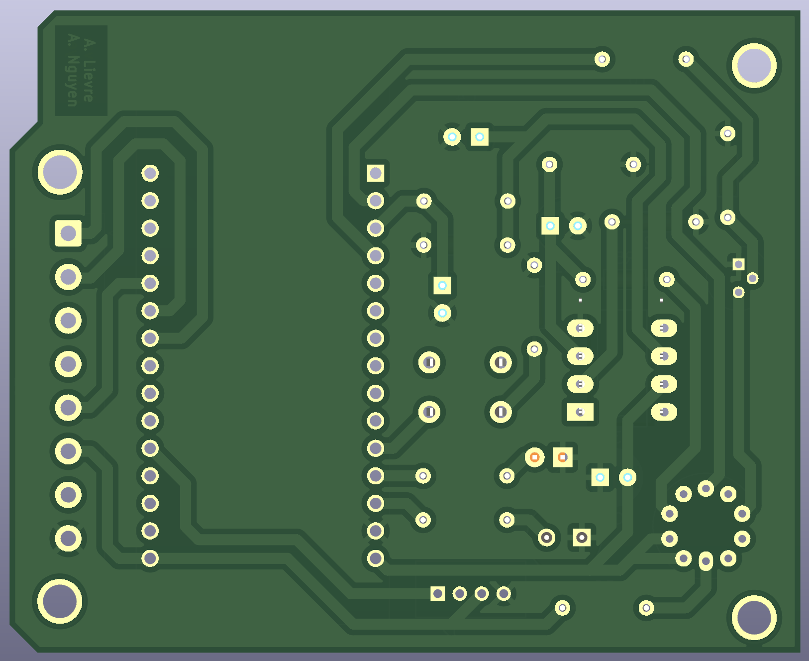
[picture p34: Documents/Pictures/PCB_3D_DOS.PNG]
PCB_3D_DOS


## Node-RED 

Finally, we needed a dashboard to display the data and the controls of the sensor. For that, we used to code in the LoRa part because since we didn't have the AIME sensor, we could only use the grove sensor.
Here is a screenshot of the dashboard we created :

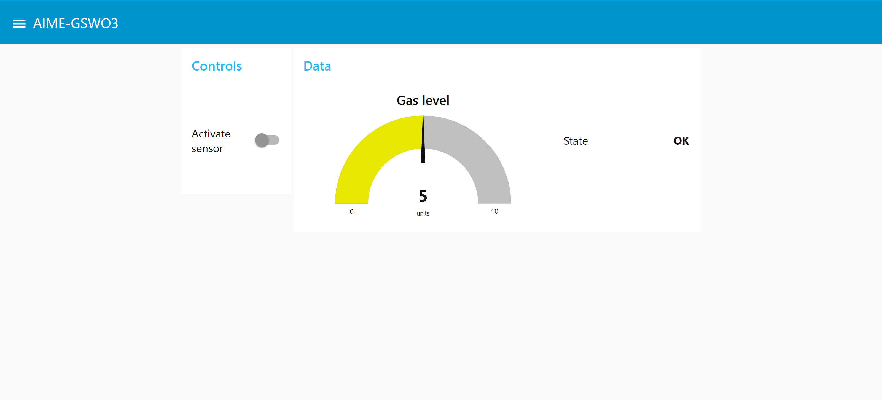
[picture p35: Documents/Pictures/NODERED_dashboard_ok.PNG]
NODERED_dashboard_ok


It is a simple dashboard that displays the gaz level. In the next picture, you can see the "warning" mode:

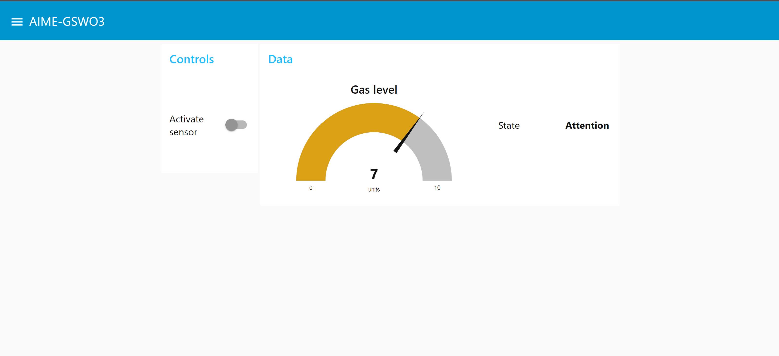
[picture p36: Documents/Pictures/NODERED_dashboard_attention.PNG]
NODERED_dashboard_attention


On the left, we also put a "Controls" module to implement a potential control of the sensor and/or the buzzer directly on the dashboard.

Here is a screenshot of the Node-RED flow:

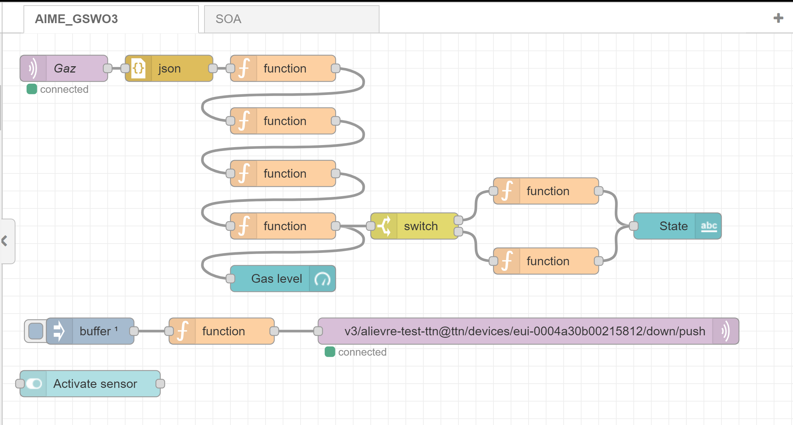
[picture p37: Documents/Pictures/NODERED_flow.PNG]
NODERED_flow


You can find the flow's code [here](https://github.com/MOSH-Insa-Toulouse/2021_2022_LIEVRE_NGUYEN/blob/main/4_Piste_noir/flows_AIMEGSWO3.json)

## Datasheet 

You can find the datasheet [here](https://github.com/MOSH-Insa-Toulouse/2021_2022_LIEVRE_NGUYEN/blob/main/Documents/Datasheet_AIME_GSWO3.pdf)

## Possible improvements 

Of course, there are a few improvements that could be done to this project:

1. we are a bit disappointed not to have been able to really make the PCB board because we put a lot of time and work to create the best PCB board possible. 
2. if we had the PCB board, it would have been fun to test our gas sensor with our real code to see the result of all our work.
3. it would also have been nice to develop our dashboard a little more (for example, implement the "Controls" module to control the sensor and the alarm).
4. the cherry on top would also have been to develop an Android app to display and control our sensor module on our phone.

## Contacts 

**Agathe LIEVRE & Assia NGUYEN**

- 5th year students from INSA Toulouse

- _lievre@insa-toulouse.fr_

- _asnguyen@insa-toulouse.fr_

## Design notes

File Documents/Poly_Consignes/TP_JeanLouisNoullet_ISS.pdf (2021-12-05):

# ISS - UF Smart Devices : partie analogique

English version here

## 1. Mesure d'une résistance

Méthodes classiques :

- imposer I, mesurer V
- imposer V, mesurer I
- alimenter, mesurer V et I
- alimenter, mesurer R par identification (pont)

Cas du capteur de gaz à nano-particules :

- très faible courant : de l'ordre de 100 nA
- effet tunnel : forte non-linéarité de I(V)

Alors quelle technique adopter pour extraire l'information utile du capteur ?

## 2. Mesure de faible courant avec un micro-contrôleur

Parametres des microcontrôleurs courants en 2016
(AVR/Arduino, STM32, PIC Microchip, etc...) :
- résolution 10 à 12 bits (1024 à 4096 points)
- pleine échelle (VRef) de 1.1 V à 5.0 V
- impédance de source max 1 kOhm à 10 kOhm
- fréquence d'échantillonnage max 15 kHz à 2.4 MHz
La mesure directe d'un courant de 100 nA ne parait pas praticable.
N.B. la valeur max d'impédance de source est spécifiée en fonction de l' échantillonneur à capacité commutée présent à l'entrée de l'ADC.

Solution "classique" :

L'amplificateur transimpédance.

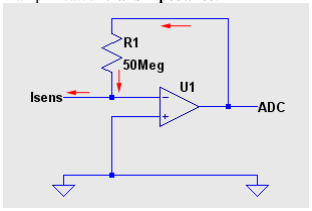
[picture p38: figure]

Problèmes posés par cette solution :

- nécessite une très grande valeur pour R1
- nécessite une tension négative pour alimenter le capteur

Solution "classique" améliorée :

L'amplificateur transimpédance suivi d'un étage amplificateur inverseur.

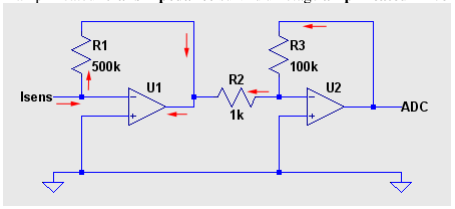
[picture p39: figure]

- grâce au gain du second étage, la résistance R1 n'a pas besoin d'être grande
- grâce à l'inversion, l'alimentation du capteur peut être positive
- cependant il faut une alimentation bipolaire pour les amplis

Solution minimaliste :

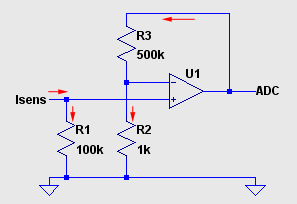
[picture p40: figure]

- conversion I-->U dans la résistance d'épreuve R1 (shunt)
- amplification à fort gain par montage non-inverseur
- la chute de tension sur R1 perturbe (un peu) la tension appliquée au capteur
- peut fonctionner avec seulement une alimentation positive

Remarques :
Gain de l’étage de l’AOP : (R2+R3)/R2=(1k+500k)/1k=501
Tension aux bornes de R1 : le courant Isens est d’environ 100nA
- V = 100kOhm*100nA=10⁻²V=10mV
Tension sur l’ADC : Gain*Tension aux bornes de R1 => 501*10x10⁻³~5V

Contraintes sur le choix de l'ampli :

- faible courant d'entrée

- ultra-faible offset de tension
- supporte mode commun à la tension d'alim négative ("low rail")

Remarques :
(1) offset voltage = erreur constante aux entrées de l’amplificateur différentiel dû à un état non compensé sur l’étage d’entrée de l’amplificateur. On veut que cet offset soit négligeable devant la tension mesurée sur R1 qui sera de 10mV.
(2) Le courant d’entrée doit être très petit devant Isens pour avoir le Isens traverse la R1 et pas l’entrée
(3) Mode commun : tension commune aux deux entrées, un bon amplifieur sera insensible à ce mode commun. Si le Isens =0A ,on veut 0V sur l’ADC. LTC1050C => 5µV offset voltage, et maximum offset voltage drift : 0.05µV/°C. Bien comparé aux 10mV aux bornes de R1.

L'ampli LTC1050C est disponible, satisfait-il ces contraintes ?

## 3. Filtrage passe-bas

Une bande passante de l'ordre de 1 Hz est largement suffisante pour extraire toute l'information utile du capteur, dont l'inertie est importante.

Un montage aussi sensible étant très vulnérable au bruit à 50Hz (+ harmoniques) résultant du couplage capacitif avec le réseau 230V, un filtrage passe-bas est indispensable.
D'autres sources de bruit à filtrer sont les horloges de circuits digitaux (microcontrôleur, afficheurs, etc...) et les transceivers RF (bluetooth, etc...).

Ce filtrage peut être effectué en partie du coté digital, par programme, sur le microcontrôleur.
Cependant un filtrage analogique est indispensable, en effet un excès de bruit à l'entrée de l'ADC pourrait amener celui-ci à saturation.
De plus un filtrage anti-repliement (anti-aliasing) est indispensable en raison de l'échantillonnage effectué par l'ADC.
Pour faciliter ce filtrage on a intérêt à faire fonctionner l'ADC à la plus GRANDE fréquence utilisable SANS PERTE DE QUALITE (dans le cas de l'Arduino Uno, 200kHz/13 = 15.4 kHz, avec un choix de prescaler à 128 ! (cf wiring.c).

Le filtrage peut s'implanter dans 3 régions de la chaîne de traitement analogique :

- filtre passif à l'entrée : permet d'éviter que les bruits HF causent de la distorsion dans les étages d'entrée
- filtre actif basé sur les amplificateurs opérationnels : maximum d'efficacité
- filtre passif en fin de chaine, coté ADC, pour retirer le bruit introduit en cours de traitement (bruit d'alimentation, bruit d'horloge des amplificateurs à découpage)

Schéma Suggéré

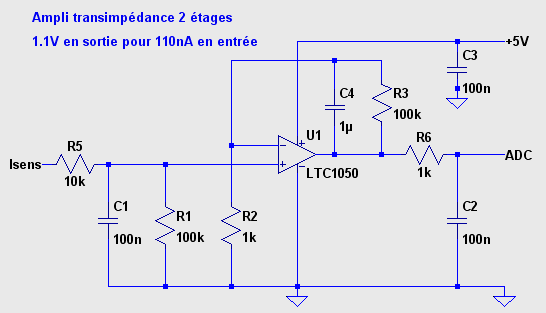
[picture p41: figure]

- R5 en entrée protège l'ampli opérationnel contre les décharges électrostatiques, en forme avec C1 un filtre pour les bruits en tension
- C1 avec R1 forme un filtre pour le bruit en courant
- R2 sera interchangeable, pour permettre une adaptation du calibre
- C4 avec R3 forme un filtre actif
- C2 avec R6 forme le filtre de sortie
- C3 filtre le bruit d'alimentation

## 4. Questions

A l’aide du simulateur LTSpice IV :

1. Vérifier la fonctionnalité dans les conditions nominales 2. L'incidence de l'offset de l'amplificateur LTC1050C est-elle acceptable ? 3. L'incidence du courant d'entrée de l'amplificateur est-elle acceptable ? 4. Quelle est la fréquence de coupure de chaque étage de filtre passe-bas ? 5. Quelle est l'atténuation globale d'un bruit en courant de 50 Hz ?

6. Quelle est l'atténuation globale d'un bruit en courant à la fréquence limite de repliement (dans le cas de l'ADC Arduino Uno) ?

### 7. Préparez une simulation de démonstration avec :

- un capteur alimenté en 5V dont la conductance varie de 10 nS à 20 nS en 0.5s (l’utilisation d’un filtre passe-bas pourrait être utile !).

### 1. Mettre en évidence l’intérêt du filtrage 50Hz choisi en visualisant

l’impact d’un bruit de 1% sur la source d’alimentation du capteur

### 2. Quand est-ce que ce bruit devient gênant ?

- Pour s’approcher des conditions réelles de mesures réalisées à l’AIME, vous modifierez le montage précédent pour mettre une alimentation de 20V sur le capteur (à la place de la 5V) et conserverez l’alimentation de 5V sur l’AOP.

### 1. Peut-on réaliser ce montage sur un Arduino Uno ?

- une source de bruit de 230V RMS à 50Hz, couplée au noeud d'entrée par une capacité de 1 pF
- Serait-il intéressant d’ajouter un montage dérivateur pour mesurer directement le coefficient cinétique de la réaction chimique du capteur avec un gaz ?

### 1. Si oui, proposez un montage !

N.B. pour simuler une conductance variable, utiliser l'élément Arbitrary current source (symbole BI) de LTSpice contrôlé par une source de tension indépendante représentant la variation de concentration du gaz atteignant le capteur

8. Donner une expression analytique de la résistance du capteur en fonction des éléments du circuit transimpédance.

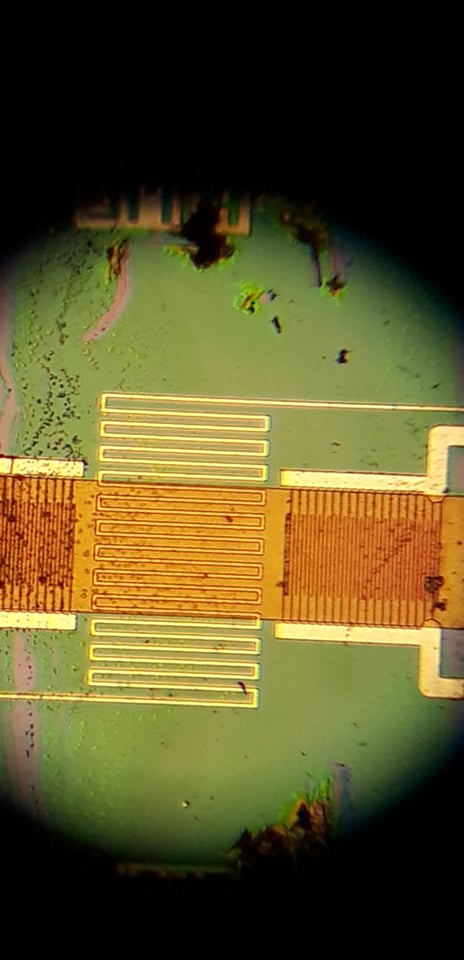
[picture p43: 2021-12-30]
Documents/Pictures/AIME_GSWO3_3.jpg

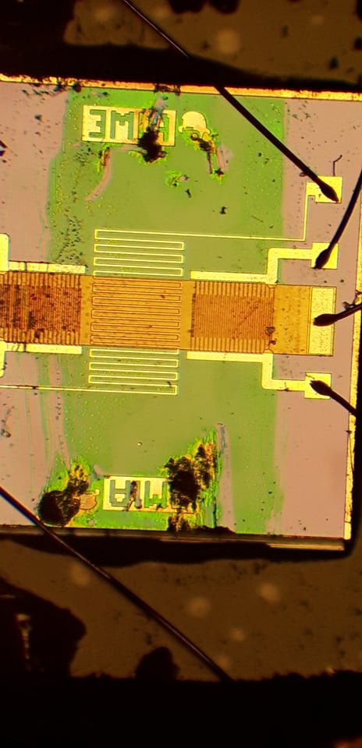
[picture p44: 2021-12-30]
Documents/Pictures/AIME_GSWO3_2.jpg

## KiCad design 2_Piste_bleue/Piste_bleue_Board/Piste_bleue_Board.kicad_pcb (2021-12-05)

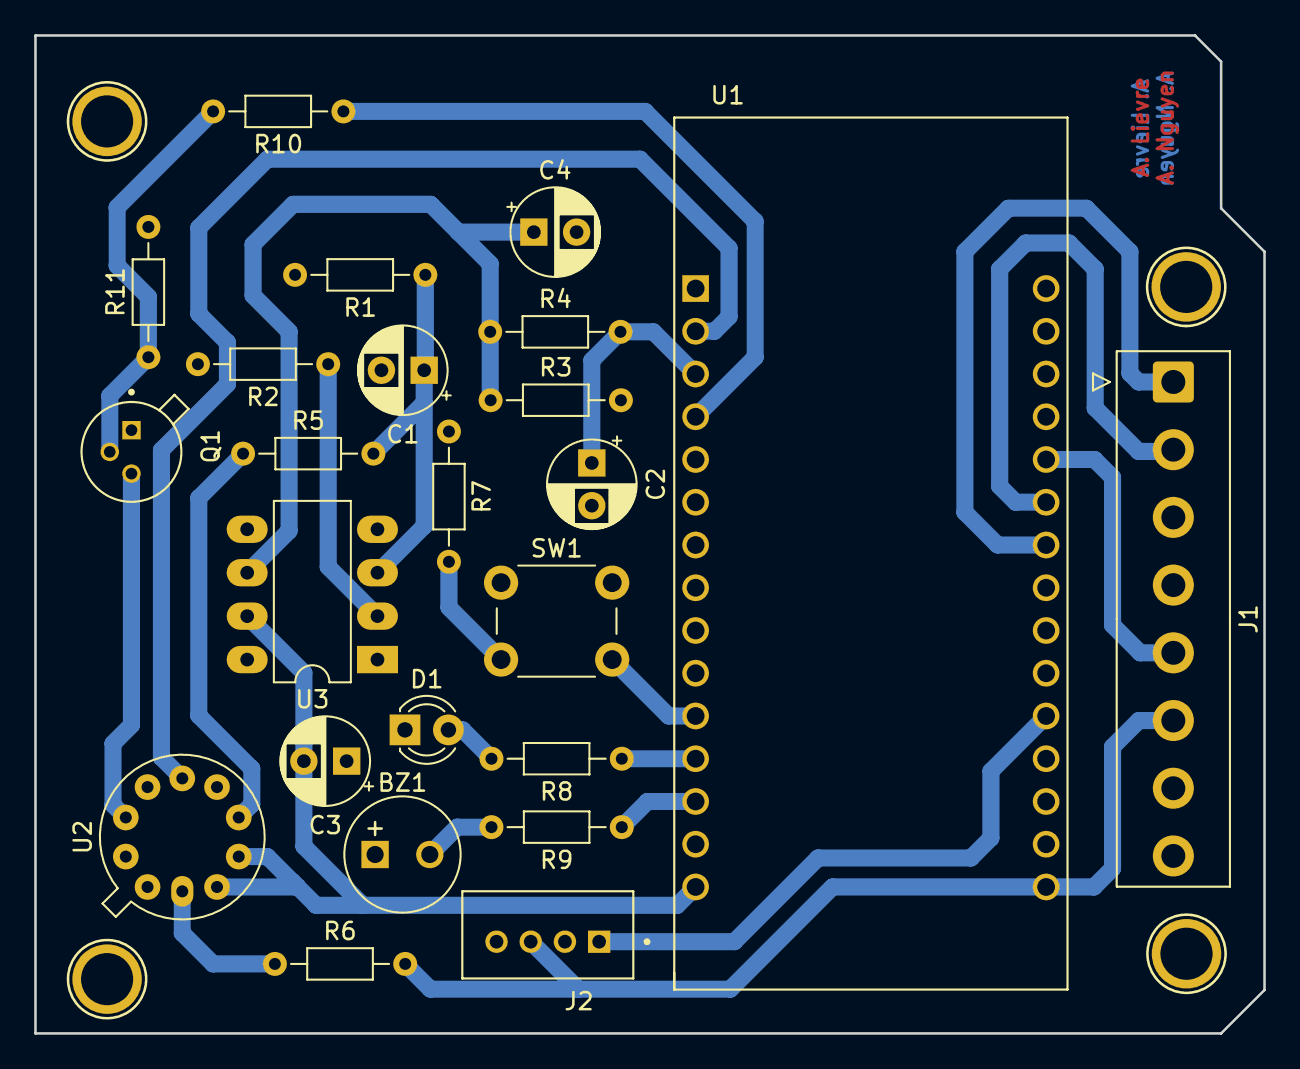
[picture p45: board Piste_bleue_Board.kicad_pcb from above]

Board: 2 copper layers, 71.9 x 58.4 mm, 28 parts (0 on the bottom side), 23 nets.

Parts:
BZ1: Buzzer; MagneticBuzzer_Kingstate_KCG0601
C1, C2, C3: 100n; CP_Radial_D5.0mm_P2.50mm
C4: 1u; CP_Radial_D5.0mm_P2.50mm
D1: LED; LED_D3.0mm
J1: Conn_01x08_Female; TE_826576-8_1x08_P3.96mm_Vertical
J2: Conn_01x04_Female_Grove; SEEED_110990030
P5, P6, P7, P8: CONN_01X01; Arduino_1pin
Q1: 2N2222; TO127P584H533-3
R1, R3: 100k; R_Axial_DIN0204_L3.6mm_D1.6mm_P7.62mm_Horizontal
R2, R4: 1k; R_Axial_DIN0204_L3.6mm_D1.6mm_P7.62mm_Horizontal
R5, R7, R8, R9: 10k; R_Axial_DIN0204_L3.6mm_D1.6mm_P7.62mm_Horizontal
R6, R10, R11: ?; R_Axial_DIN0204_L3.6mm_D1.6mm_P7.62mm_Horizontal
SW1: SW_Push_Dual; SW_PUSH_6mm_sensor
U1: ESP32-DEVKITC-32D; ESP32_DEVKIT_SENSOR_GAS
U2: gas_sens; Sensor_gas_package
U3: LTC1050ACN8#PBF; DIP-10_W7.62mm_LongPads

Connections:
3V3: J1.6 (3V3), J2.3 (Vcc), R6.2, U1.30 (3V3)
5V: C3.2, U1.15 (EXT_5V), U2.2 (R_Sens_1_In), U2.3 (R_Poly_IN), U3.7 (V+)
ADC1_6: R10.1, U1.4 (IO34)
Cmd: Q1.3, U2.8 (R_Poly_Out)
GND: BZ1.1 (-), C1.2, C2.2, C3.1, C4.2, D1.1 (K), J1.8 (Gnd), J2.4 (Gnd), Q1.1, R1.2, R2.2, R3.2, R7.1, R11.2, U1.14 (GND), U3.4 (V-)
unnamed: BZ1.2 (+), R9.2
unnamed: C1.1, R1.1, R5.2, U3.3 (+IN)
unnamed: C2.1, R4.2, U1.3 (SENSOR_VN)
unnamed: C4.1, R3.1, R4.1, U3.6 (OUT)
unnamed: D1.2 (A), R8.2
unnamed: J1.1 (Tx), U1.22 (IO18)
unnamed: J1.2 (Rx), U1.21 (IO19)
unnamed: J1.5 (RST), U1.20 (IO21)
unnamed: R2.1, U3.2 (-IN)
unnamed: R5.1, U2.4 (R_Sens_1_Out)
unnamed: R6.1, U2.1 (R_ALU_IN)
unnamed: R7.2, SW1.3
unnamed: R8.1, U1.12 (IO12)
unnamed: R9.1, U1.13 (IO13)
unnamed: Q1.2, R10.2, R11.1
unnamed: SW1.4, U1.11 (IO14)
unnamed: U1.2 (SENSOR_VP), U2.6 (R_Alu_Out)
unnamed: J2.1 (Sig), U1.26 (IO4)

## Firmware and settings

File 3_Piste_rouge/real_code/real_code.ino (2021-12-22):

#include <Arduino.h>
#include "rn2xx3.h"

#define RST 21 //Pin de reset du module LORA
#define RX 18  //Pin RX du module LORA
#define TX 19  //Pin TX du module LORA
#define INTERRUPT_PIN 12 //Pin d'interruption du capteur de GAZ
#define SIG_grove 2  //Signal d'entree du capteur grove (industriel)
#define Buzz_pin 17  //Pin de sortie du buzzer
#define R_Poly_CMD 16 //Pin de la sortie de commande de la resistance de chauffe (Polysilicium)
#define ADC_SENS 33 // Pin d'entree du signal du capteur de gaz (AIME)
#define ADC_R_Alu 27 //Pin d'entree de la resistance d'ALUMINIUM (capteur de temperature)

int a; //
int b; // R_aluminium = a * T(Kelvin) + b 
String AppEUI = "44E53245F1200CDEEC2525661C76BA38"; //AppEUI du reseau sur TTN
String AppKey = "0000000000000000"; //AppKey du reseau TTN
rn2xx3 myLora(Serial2); //Constructeur de la classe rn2xx3
byte payload[4]; //Payload a envoyer sur TTN
float R0=0.45; //Resistance du module grove en environement ambiant
float sensor_grove_volt; //conversion en volt de l'entree du signal du capteur grove
float sensor_aime_volt; //conversion en volt de l'entree du signal du capteur AIME
float RS_gas; //recoit la valeur de RS dans le gaz
float ratio; // Get ratio RS_GAS/RS_air
int duty_cyle; //duty cycle du signal PWM pour la commande de la resistance de chauffe
int t_1 = 0; //timestamp 1
int t_2 = 0; //timestamp 2
int delta_t=t_2 - t_1; // delta time
double Kp, Ki, Kd; //Ponderations du PID (à definir en observant la reponse du systeme)
float e_t = 0; //mesure de l'erreur a t
float e_t_1 = 0; //mesure de l'erreur a t-1
uint32_t grove_data; //donnée capteur grove
uint32_t aime_data;  //donnée capteur AIME
int R1; //
int R2; //
int R3; //
int R5;  //Resistances du circuit de conditionnement selon la meme numerotation que dans KICAD !
int Vcc; // A definir en fonction des grandeurs electriques voulues
int R6; //
const uint32_t PWM_OUT = 16;  //Pin de sortie de la commande PWM de la resistance de chauffe
// setup des propriétés PWM
const uint32_t freq = 20000;
const uint32_t ledChannel = 0;
const uint32_t resolution = 8;

void initialize_radio() //Initialization du module LORA
{
  //Reset du module
  pinMode(RST, OUTPUT);
  digitalWrite(RST, LOW);
  delay(100);
  digitalWrite(RST, HIGH);
  delay(100); //Attente du message de start du module LORA
  Serial2.flush();
  //check de la communication avec la radio
  String hweui = myLora.hweui();
  while(hweui.length() != 16)
  {
    Serial.println("Communication with RN2xx3 unsuccessful. Power cycle the board.");
    Serial.println(hweui);
    delay(10000);
    hweui = myLora.hweui();
  }
  //Recuperation de HWEUI pour la configurer sur TTN
  Serial.println("When using OTAA, register this DevEUI: ");
  Serial.println(hweui);
  Serial.println("RN2xx3 firmware version:");
  Serial.println(myLora.sysver());
  //message de debug de type "en attente de connexion"
  Serial.println("Trying to join TTN");
  bool join_result = false;
  //OTAA: initOTAA(String AppEUI, String AppKey);
  join_result = myLora.initOTAA(AppEUI, AppKey);
  while(!join_result)
  {
    Serial.println("Unable to join. Are your keys correct, and do you have TTN coverage?");
    delay(60000); //delay d'une minute avant retry 
    join_result = myLora.init();
  }
  Serial.println("Successfully joined TTN");
  }

void manage_interrupt() //gestion de l'interruption du capteur
{
  digitalWrite(Buzz_pin, 1); //active l'alarme a la detection du GAZ (interruption materielle)
}

uint32_t read_grove_sensor () //Recuperation de la donnée du capteur grove
{
  int sensor_groove_Value = analogRead(SIG_grove); 
  sensor_grove_volt=(float)sensor_groove_Value/4096*5.0; //conversion en tention
  RS_gas = (5.0-sensor_grove_volt)/sensor_grove_volt; // TAUX VARIATION RESISTANCE SELON GAZ
  ratio = (RS_gas/R0);  // ratio = RS/R0
  uint32_t data=ratio*100;
  return data;
}

uint32_t read_aime_sensor () //Recuperation de la donnée du capteur AIME
{
  int sensor_aime_Value = analogRead(ADC_SENS);
  sensor_aime_volt=(float)sensor_aime_Value/4096*5.0;
  float R_capteur=(R1*(R2+R3)*Vcc/(R2*sensor_aime_volt)) -R1-R5; //formule justifiée en TD
  return R_capteur;
}

uint32_t read_r_alu () //Recuperation de la donnée du capteur de temparateur (R ALU)
{
  int ADC_R_ALU = analogRead(ADC_R_Alu);
  float ADC_R_ALU_volt=(float)ADC_R_Alu/4096*5.0;
  float R_Alu=ADC_R_ALU_volt*R6/(3.3-ADC_R_ALU_volt);
  return R_Alu;
}

void config_PWM() // configure des fonctionnalités PWM
{
  ledcSetup(ledChannel, freq, resolution);
  ledcAttachPin(PWM_OUT, ledChannel); //Liaison de la chaine du Timer avec la pin utilisée
}

float temperature () // mesure de la temperature du capteur en fonction de R aluminium
{
  float T = a*(read_r_alu()) + b;
  T = T - 273; //conversion en Celcius
  return T;
}

int manage_PID() //Correcteur PID pour maintenir la temprature a 200 degrés celcius
{
  int t_2 = micros();
  e_t = 200 - temperature();
  float e_P = Kp * e_t;
  float e_I = Ki * e_t * delta_t; 
  float e_D = Kd * (e_t - e_t_1) / (delta_t);
  t_2 = t_2;
  e_t_1 = e_t;
  uint8_t C = e_P + e_D + e_I;
  if(C > 255) C = 255; //Pour borner la correction entre 0 et 255
 
  return C; //Duty cycle de la PWM de commande
}

void Cmd_PWM_Poly() //Commande de la resistance de chauffe en PWM
{
  int duty_cycle=manage_PID();
  ledcWrite(ledChannel,duty_cyle);
}

void setup() {
  Serial.begin(9600); //initialisation moniteur serie (ESP - PC)
  config_PWM(); //configuration de la PWM
  Serial2.begin(57600, SERIAL_8N1, RX, TX); //initialisation moniteur serie 2 (LORA - ESP)
  initialize_radio(); //initialiation de la radio
  Serial2.print("sys get hwei\r\n"); // recuperation du HWEUI
  Serial.println(Serial2.readStringUntil('\n'));
  attachInterrupt(INTERRUPT_PIN, manage_interrupt, LOW); //Appel de la fonction d'inerruption
  
}

void loop() {
  grove_data=read_grove_sensor();
  aime_data=read_aime_sensor();
  payload[0] = highByte(grove_data);
  payload[1] = lowByte(grove_data);
  payload[2]=highByte(aime_data);  
  payload[1]=lowByte(aime_data);
  myLora.txBytes(payload,4); 
}

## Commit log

2021-11-26 - On a fini la piste verte - On a fait la partie TTN de la piste bleue
2021-11-30 Composants Kicad
2021-11-30 Projet Kicad
    [Piste_bleue_Board.kicad_pcb, Piste_bleue_Board.kicad_sch]
2021-12-05 Nettoyage des dossiers Ajout de documents utiles (datasheet, pinout, sujets de TP...) Fin du schéma et du PCB
    [Piste_bleue_Board.kicad_pcb, Piste_bleue_Board.kicad_sch]
2021-12-22 Nettoyage des dossiers Ajout du code qui aurait été utilisé avec la board et le capteur produit durant la semaine AIME
    [Piste_bleue_Board.kicad_sch]
2021-12-30 Ecriture de la première partie du README Ajout de la datasheet
2021-12-30 Tri des dossiers Ajout de photos
2021-12-30 Changement des noms des dossiers Ajout de photos et de liens dans le README
    [Piste_bleue_Board.kicad_pcb, Piste_bleue_Board.kicad_sch]
2021-12-30 Ajout des deux derniers paragraphes
2021-12-30 Ajustement des tailles des photos
2021-12-30 Correction code piste bleue - code complet avec PID correct
    [Piste_bleue_code.ino]
2022-01-02 Correction sur le attachInterrupt
    [Piste_bleue_code.ino]
2022-01-05 Update Piste_bleue_code.ino
    corrections ultimes
    [Piste_bleue_code.ino]
2022-01-10 Fin de piste noire (Node-Red) Ajout de photos et de la datasheet
2022-01-11 Ajout dans le readme Modification de la photo du dashboard
2022-01-11 Fin du readme Modification de photos

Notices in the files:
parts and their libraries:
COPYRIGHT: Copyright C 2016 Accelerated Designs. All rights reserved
